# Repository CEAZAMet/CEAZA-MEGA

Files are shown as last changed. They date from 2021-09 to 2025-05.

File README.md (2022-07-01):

# CEAZA Mega   [][License]

*A reliable & expandable low power data <br>
logger for scientists, based on the Arduino.*

<br>
<br>

<div align = center>

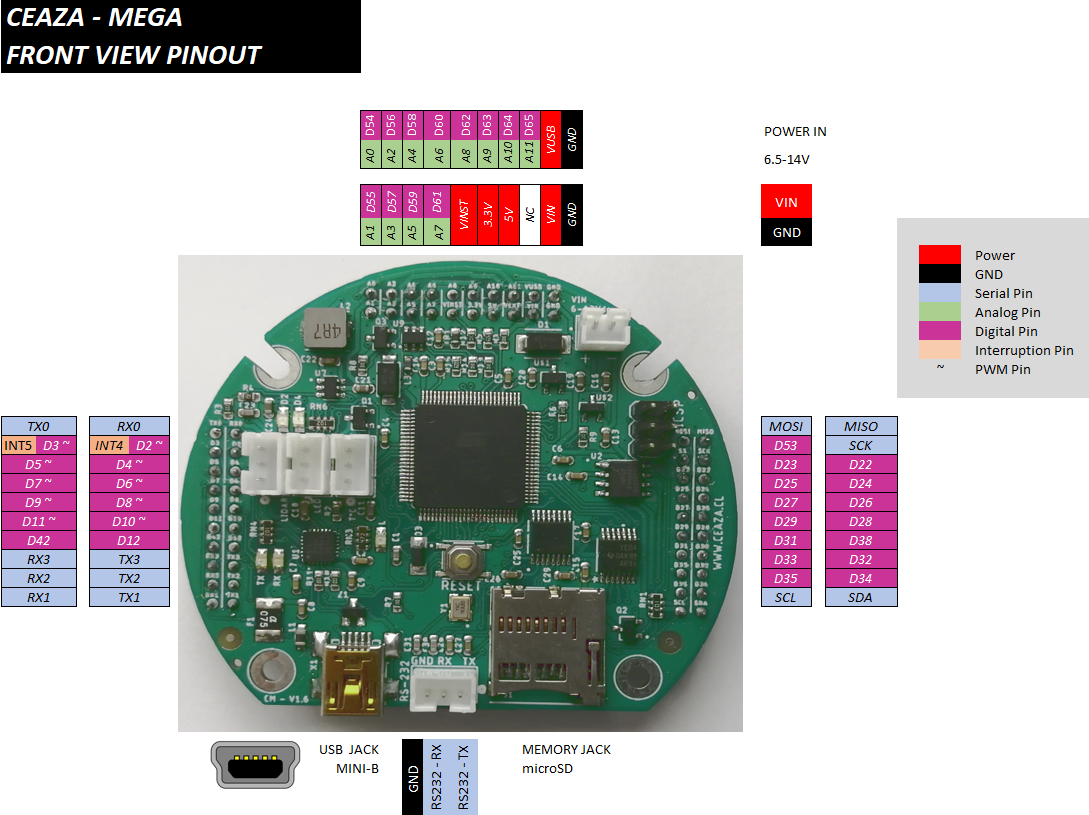
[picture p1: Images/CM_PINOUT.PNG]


</div>

<br>
<br>

## What It Is

Is a new simple, robust and expandable datalogger Arduino derivative board based in typical maker’s community integrations.  The board was designed and implemented taking into account requirements as low consumption, expandability and integration. Different tests where made so reliability in low temperatures and low energy needs are satisfied. 
Is expected that the scientific community can add this board to their tool set, as this board solves the energy problem and present an easy transition from handmade logger integrations.

CEAZA mega board integrate:
- ATMEGA2560 8-bit microcontroller
- Arduino mega 2560 bootloader for easy Arduino Ide compatibility
- A real time clock (RTC)
- A microSD card socket for data storage
- USB/Serial driver connected to UART0 for program as an Arduino mega or computer serial communication
- Serial RS-232 driver (connected to UART1) 
- Controlled high frequency (2MHz) step down switching regulator MP2451DT-LF-Z configured to deliver 5V and up to 600mA for external sensor
- Built in 10Kohm NTC thermistor for PCB temperature monitoring
- Power source system voltage monitor
- Terminal for direct connection with DS18B20 1-wire digittal temperature sensor
- 3 LEDs on board and external duplicate conection for two of those LEDs
- an ISCP terminal to program with external programer
- 3 expansion terminal for direct wires soldering or easy plug/unplug expansion boards for CEAZA MEGA

<br>

Furthermore, all integrated devices, except the main **MCU** <br>
uses a firmware controlled switched power supply in order <br>
to optimize de power consumption.

## Documentation

A comprehensive documentation for well understand, use <br>
or modify the **CEAZA MEGA** board is available in our Wiki. 

Additionally we share our schematic <br>
diagrams and Arduino example codes.

<br>
<br>

## Quickstart guide

1.  Connect a `6.5 - 14V` DC power supply.

2.  Connect the **CEAZA MEGA** main board to <br>
    the host PC with he mini-USB connector.

3.  Open the Arduino IDE.

4.  Select the Arduino Mega board <br>
    and the corresponding COM port.

5.  Open any of example sketches.

6.  Upload to the board.

<br>
<br>

## Contact & Support

For all kinds of inquiries, please contact me to <br>
my e-mail address: adrian.gallardo@ceaza.cl

<br>
<br>

## Contributing

You are welcome to contribute to the development <br>
or improvement of **CEAZA MEGA** hardware design <br>
or example application codes.

Feel free to submit a new pull request via **GitHub**.

<br>
<br>

## Academic Context

A paper with more details and performed tests was shown in **[DOI]**. 

<br>
<br>

## Disclaimer

Use **CEAZA MEGA** board and examples code at your own risk. <br>
We do not encourage any malicious use of our board.

<br>

<!----------------------------------------------------------------------------->

[Badge License]: https://img.shields.io/badge/License-MIT-yellow.svg?style=for-the-badge

[DOI]: http://doi.org/10.11591/ijres.v11.i2.pp175-187

[Preview]: Images/CM_PINOUT.PNG
[License]: LICENSE

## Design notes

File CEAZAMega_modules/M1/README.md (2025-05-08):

# Welcome to CEAZA-M1!
Wireless communication and memory backup expansion board for CEAZA MEGA.
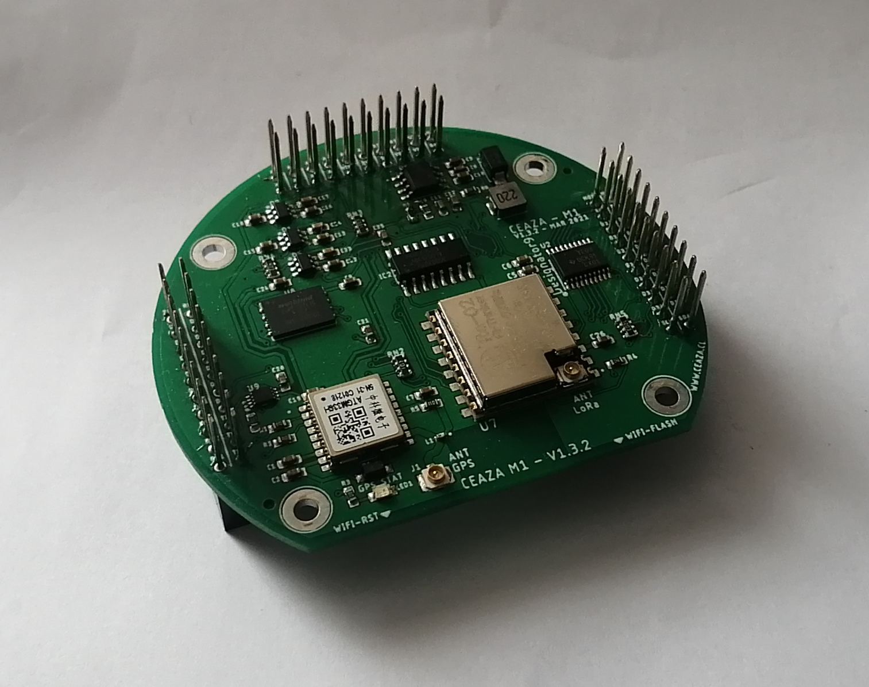
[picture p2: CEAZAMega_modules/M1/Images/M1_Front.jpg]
CEAZA M1 Board


## What is the CEAZA M1?

This design is an expansion board for CEAZA MEGA datalogger, which add the local wireless comumunication capability to the system.
The board Design integrates:
* An Ra-02 Ai-Thinker for 410-525MHz or Ra-01SH for 803MHz~930MHz LoRa Radio module.
* An ATGM336H-5N-31 GNSS GPS BDS positioning and navigation module.
* An ESP-12E WiFi module.
* A W25N01GVZEIG 1G-bit serial nand flash memory for redundant data storage.

All modules integratred are equiped with its respective power switch and power supply controlled by firmware for energy save when low power consumtions are required.
An on board jumper is included, ready to solder when the backup power source is required for GNSS module from permanent 3.3V available from CEAZA MEGA board, which increases 10uA the system power consumption.

The GNSS and WiFi modules share the same MCU UART2 thought an 74HC4052D analog multiplexer, which is controlled by firmware.

This board is pin compatible and should be connected to the CEAZA MEGA system to proper work.

## Documentation
A comprehensive documentation for well undertand, use or modify the CEAZA M1 board is available in our Wiki. In adition, we share with you the schematics diagrams, adns Arduino example codes.

## Quickstart guide
Install the M1 board in the CEAZA MEGA's bottom, make certain connection throuhg the boards by three 2 x 10 pin header terminals is rigth. 
Attach GNSS and LoRa antennas to the board, connect the power source 7 to 14 Vdc to the system.
Connect the CEAZA MEGA main board system to the host PC by mini-USB connector, open the Arduino ide software, select the Arduino Mega board and the correspondign COM port.

Open any of examples scketches and upload to the board.

# Contact and support
For all kinds of inquiries, please contact me to my e-mail address: adrian.gallardo@ceaza.cl

# Contributing
You are welcome to contribute to the development or improvement of M1 hardware design or example application codes. Feel free to submit a new pull request via github.

# Academic Context

# Licensing

# Disclaimer
Use M1 board and examples code at your own risk. We do not encourage any malicious use of our board.

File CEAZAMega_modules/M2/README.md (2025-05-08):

# Welcome to CEAZA-M2!
Prototyping board for CEAZA MEGA system.
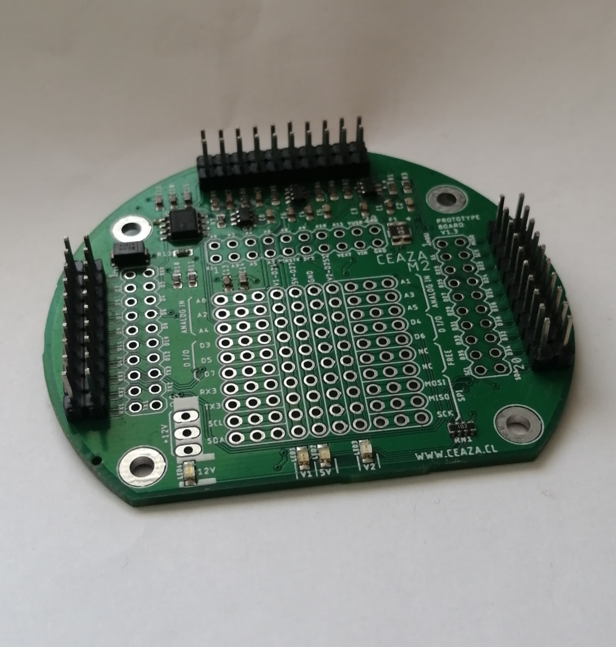
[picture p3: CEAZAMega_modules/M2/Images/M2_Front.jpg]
CEAZA M2 Board


# What is the CEAZA-M2?
Is a prototyping board with a firmware controlled +5V dedicated step-down power supply and controlled Vin pin for CEAZA MEGA system.
The board give you access to some pins as a PCB breadboard format, ready to solder any module or device.
Furthermore the board have a duplicate I/O expansion terminals to give you direct access to any of its pins.
Whith CEAZA M2 board you can easyly integrate any device to CEAZA MEGA system without any other customized board.

## Documentation
A comprehensive documentation for well undertand, use or modify the CEAZA M2 board is available in our Wiki. In adition, we share with you the schematics diagrams, adns Arduino example codes.

## Quickstart guide
Plan your electronic conection to your device, solder the necesay wires to connect your devices in the M2 board.
Install the M2 board in the CEAZA MEGA's bottom, make certain connection throuhg the boards by three 2 x 10 pin header terminals is rigth. Plug the battery and solar panel cables in the respective board terminal. be careful to avoid swap both plugs, due they are the same type of terminals. Connect the CEAZA MEGA main board system to the host PC by mini-USB connector, open the Arduino ide software, select the Arduino Mega board and the correspondign COM port.
Open any of examples scketches and upload to the board.
### WARNING!
Be careful with your breadboard conections due exist a posibility of a shortcircuit of the power supply acces in the breadboard. 
A 1A PTC Resettable fuse is placed in the main electric supply to the board (VIN pin od I/O expansion terminal) for extra electric protection.

# Contact and support
For all kinds of inquiries, please contact me to my e-mail address: adrian.gallardo@ceaza.cl

# Contributing
You are welcome to contribute to the development or improvement of M2 hardware design or example application codes. Feel free to submit a new pull request via github.

# Academic Context

# Licensing

# Disclaimer
Use M2 board and examples code at your own risk. We do not encourage any malicious use of our board.

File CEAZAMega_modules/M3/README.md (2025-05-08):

# Welcome to CEAZA-M3!
Solar charger for 12V SLA battery in CEAZA MEGA system.
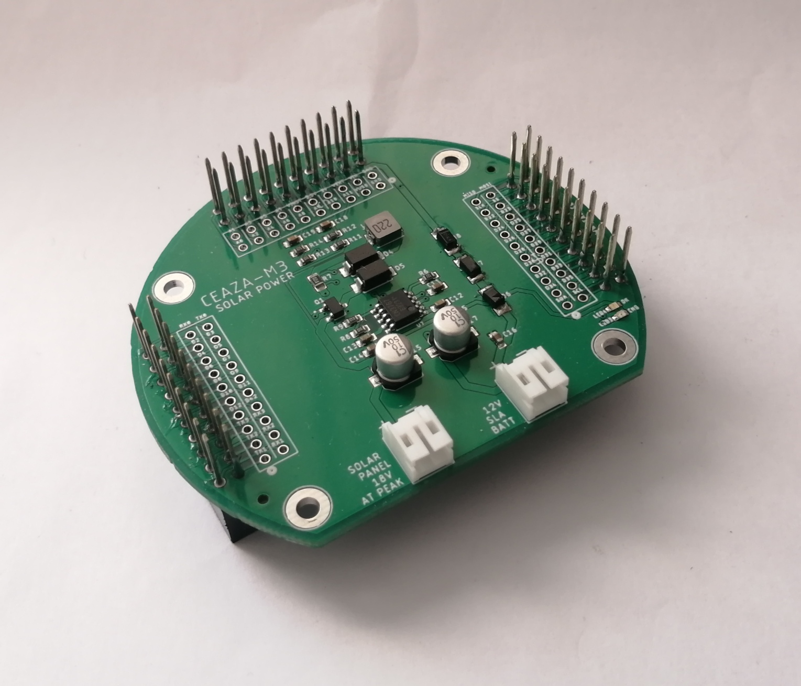
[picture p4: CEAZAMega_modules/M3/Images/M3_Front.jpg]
CEAZA M3 Board


# What is the CEAZA-M3?
Is a solar PWM charger for 12V SLA battery board compatible with CEAZA MEGA system, which allow recharge the system battery every day and avoid system failure due lack of energy storage.
The CEAZA M3 have below specs:
- Only for 12V SLA batteries.
- 18Vmpp Solar pannel (absolute maximum 28V)
- Solar pannel voltage monitor.
- Battery voltage monitor.
- Status LED red and green powered from solar panel which indicates charging or done respectively.
- Ready to solder pins for easy prototyping.

This board is pin compatible and should be connected to the CEAZA MEGA system to proper work.

## Documentation
A comprehensive documentation for well undertand, use or modify the CEAZA M3 board is available in our Wiki. In adition, we share with you the schematics diagrams, adns Arduino example codes.

## Quickstart guide
Install the M3 board in the CEAZA MEGA's bottom, make certain connection throuhg the boards by three 2 x 10 pin header terminals is rigth. Plug the battery and solar panel cables in the respective board terminal. be careful to avoid swap both plugs, due they are the same type of terminals. Connect the CEAZA MEGA main board system to the host PC by mini-USB connector, open the Arduino ide software, select the Arduino Mega board and the correspondign COM port.
Open any of examples scketches and upload to the board.
### WARNING!
Do not connect the battery in the main CEAZA MEGA power plug when you connect the M3 board. This may cause an electric problem in the system.

# Contact and support
For all kinds of inquiries, please contact me to my e-mail address: adrian.gallardo@ceaza.cl

# Contributing
You are welcome to contribute to the development or improvement of M3 hardware design or example application codes. Feel free to submit a new pull request via github.

# Academic Context

# Licensing

# Disclaimer
Use M3 board and examples code at your own risk. We do not encourage any malicious use of our board.

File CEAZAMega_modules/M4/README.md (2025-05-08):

# CEAZA-M4
Solar charger for 3.7V lithium battery in CEAZA MEGA system.

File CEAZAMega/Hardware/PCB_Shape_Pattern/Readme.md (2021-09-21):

# CEAZA mega PCB Shape Pattern
You can design your own CEAZAmega expansion board which could comply with your functional requirements.
Here they're available the eagle documents to develop a shape compatible new expansion board.

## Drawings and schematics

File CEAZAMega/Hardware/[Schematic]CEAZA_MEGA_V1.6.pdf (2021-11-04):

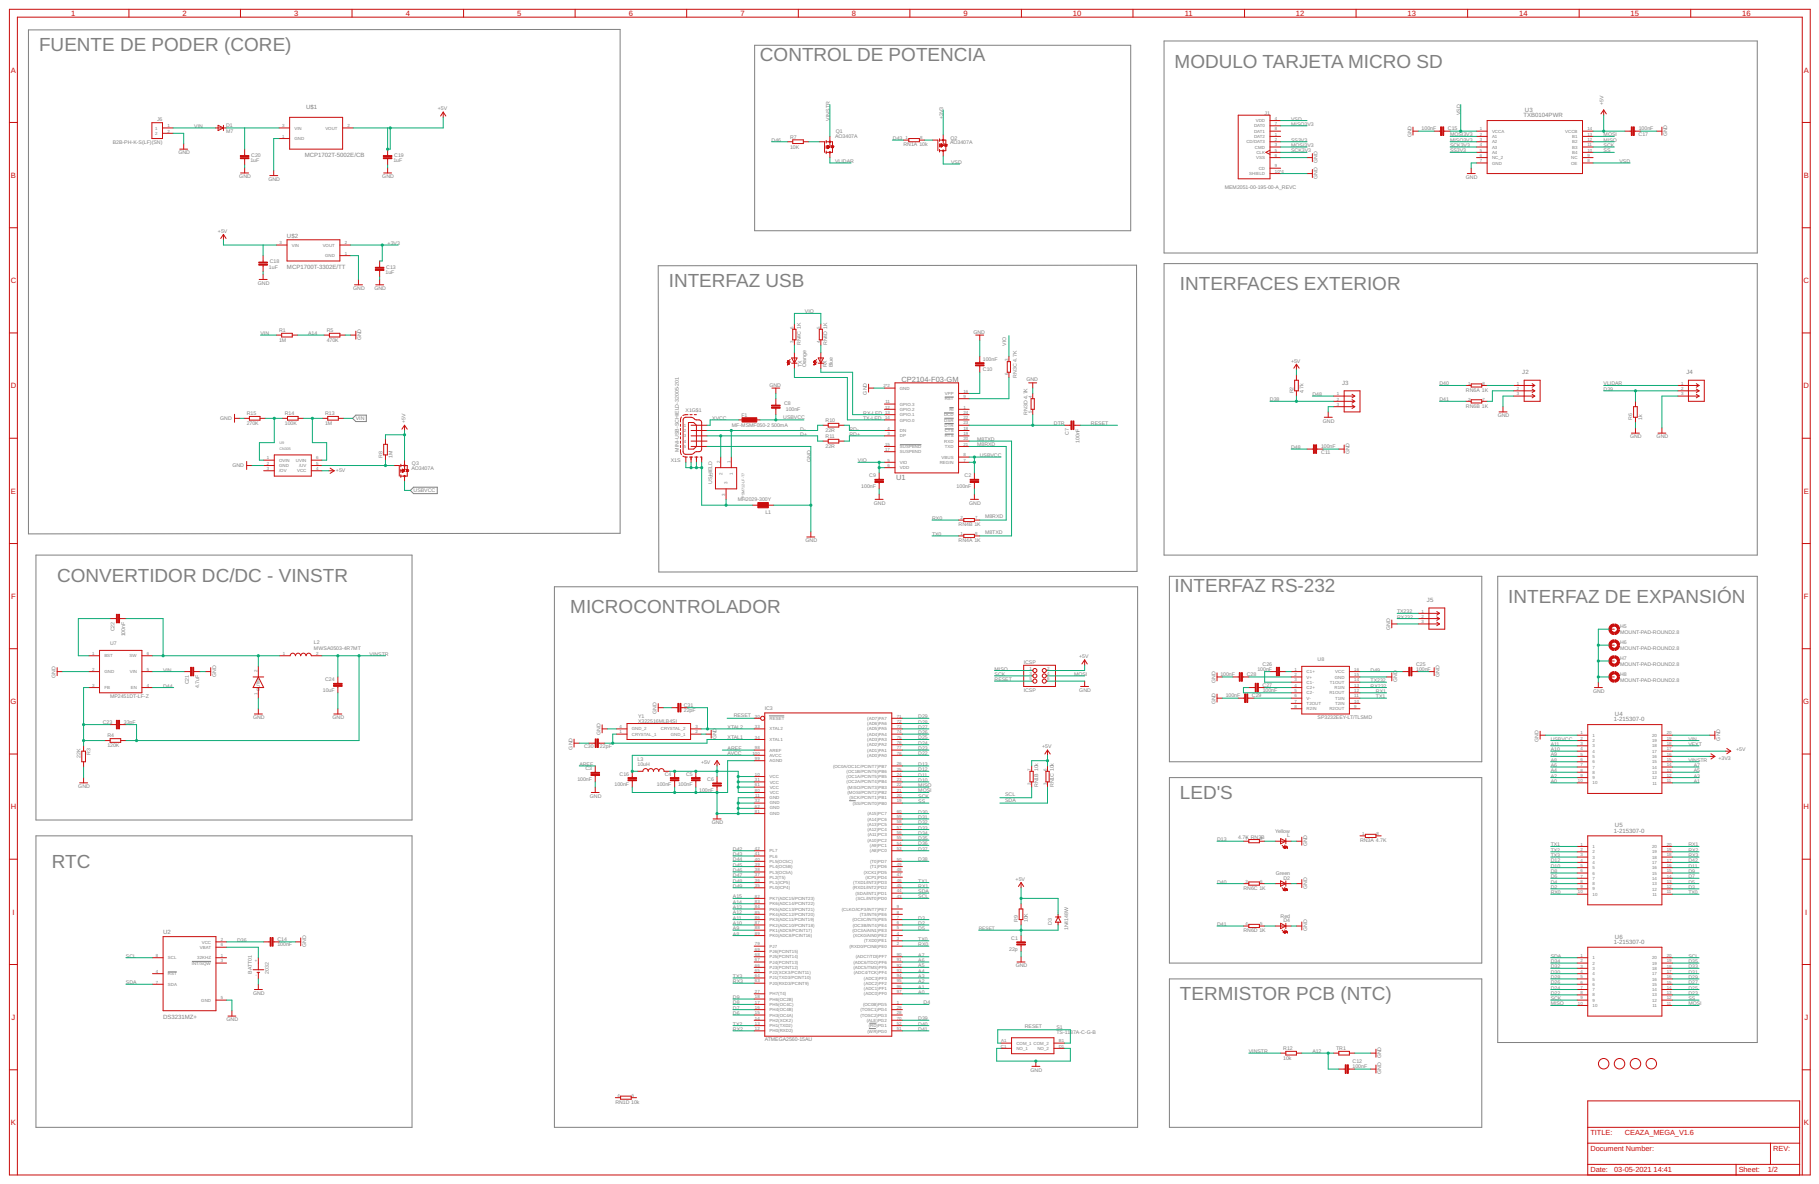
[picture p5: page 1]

FUENTE DE PODER (CORE)

SpiceOrder 1 SpiceOrder 2 MODULO TARJETA MICRO SD

CONVERTIDOR DC/DC - VINSTR

MOUNT-PAD-ROUND2.8 MOUNT-PAD-ROUND2.8 MOUNT-PAD-ROUND2.8 MOUNT-PAD-ROUND2.8 1-215307-0

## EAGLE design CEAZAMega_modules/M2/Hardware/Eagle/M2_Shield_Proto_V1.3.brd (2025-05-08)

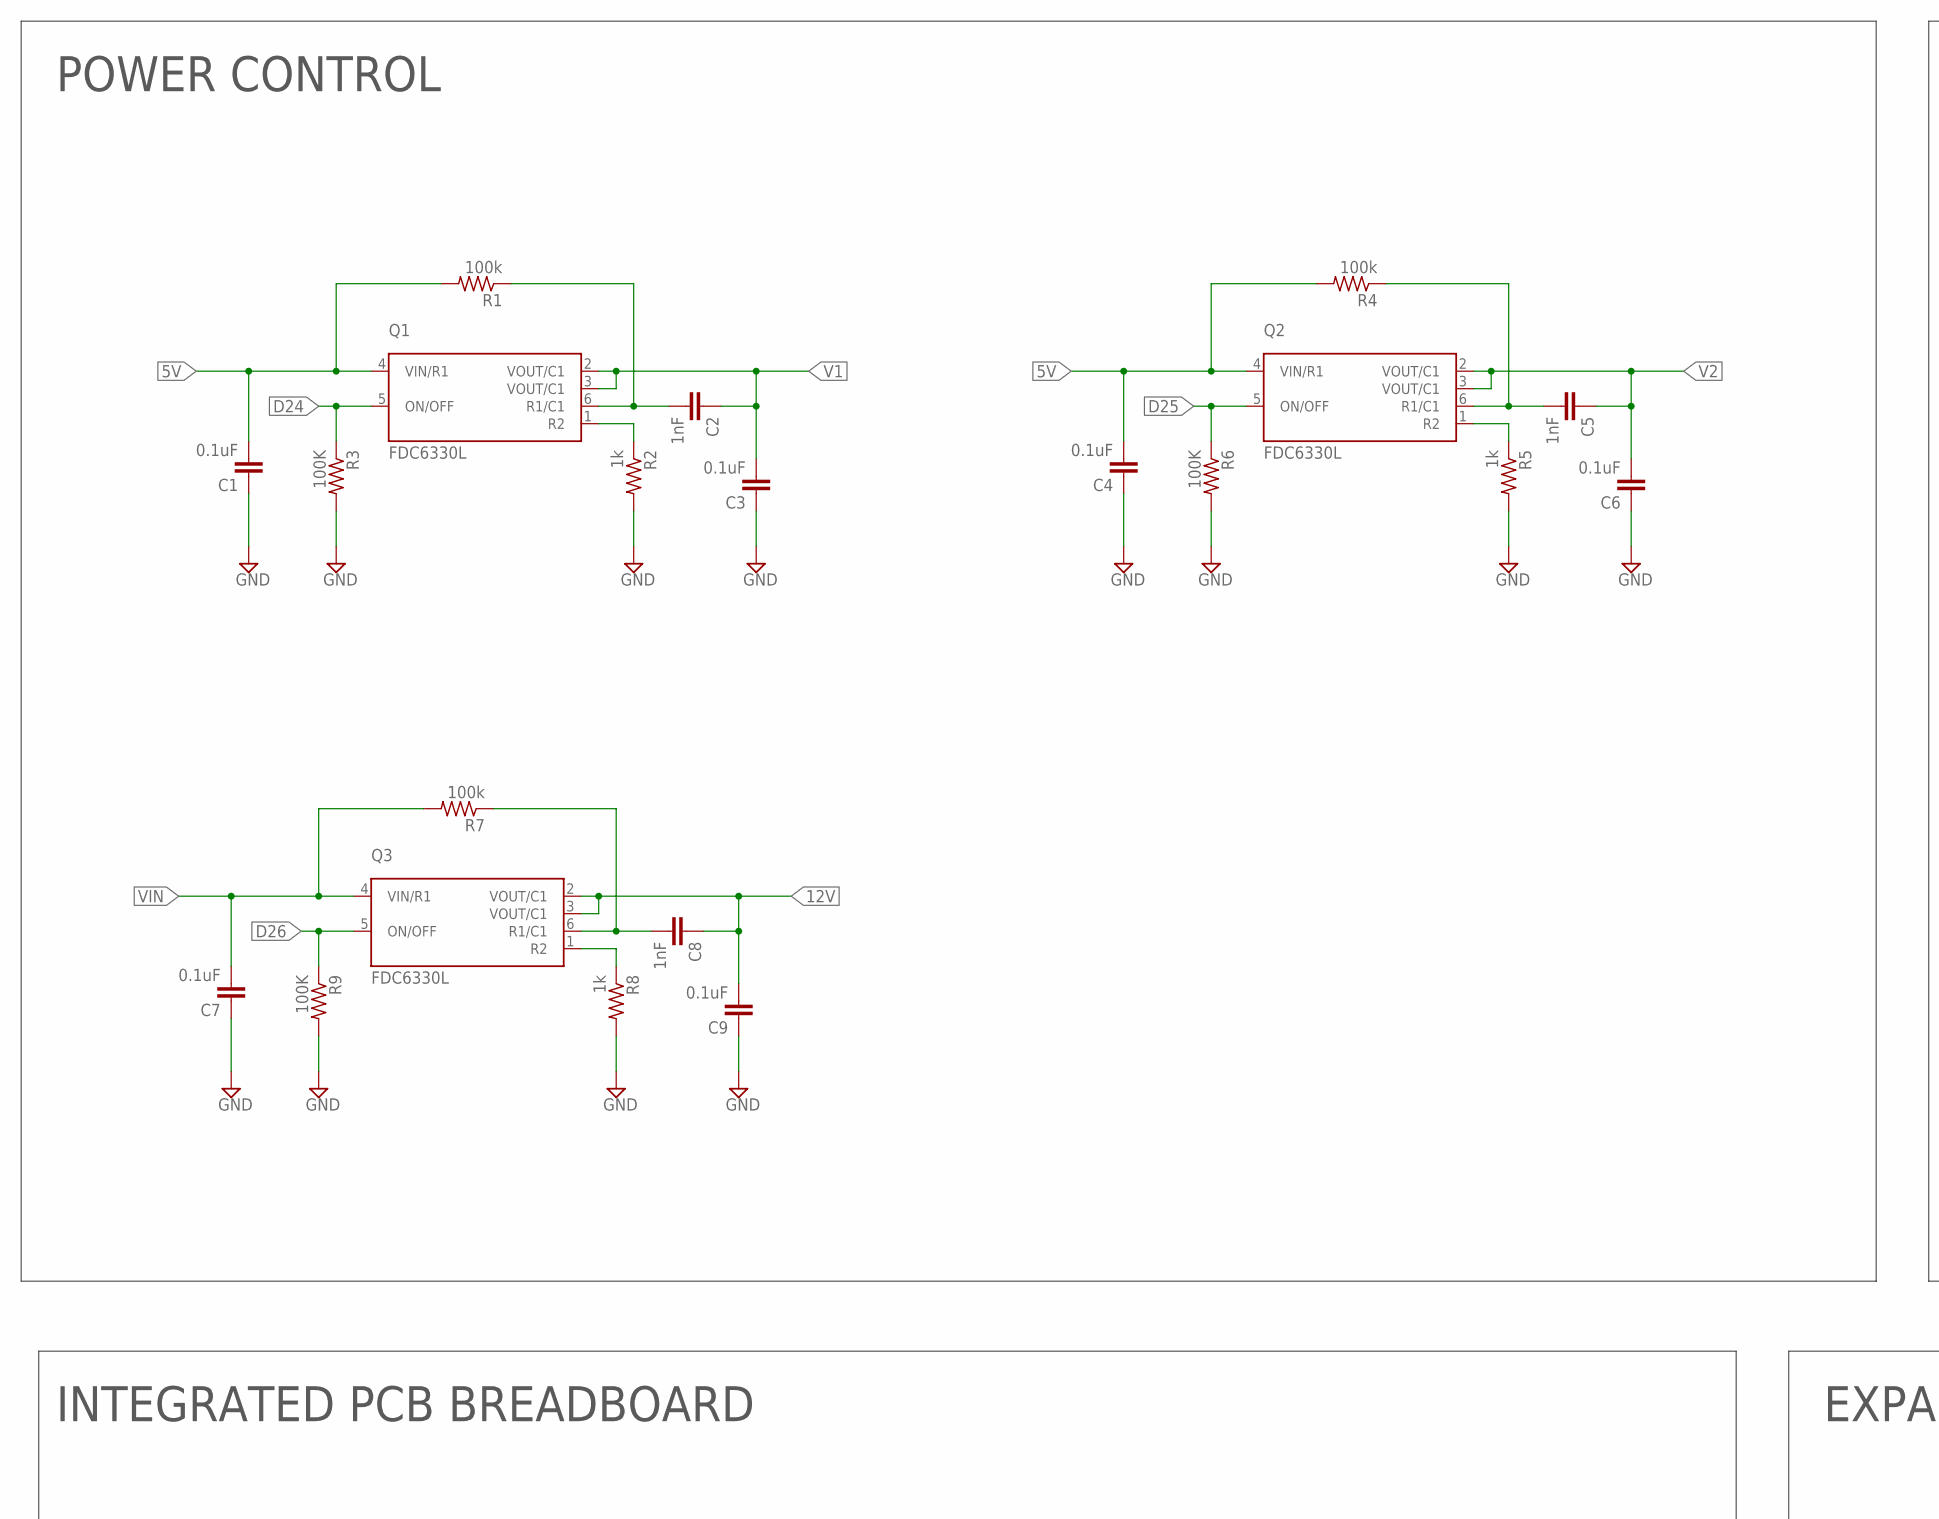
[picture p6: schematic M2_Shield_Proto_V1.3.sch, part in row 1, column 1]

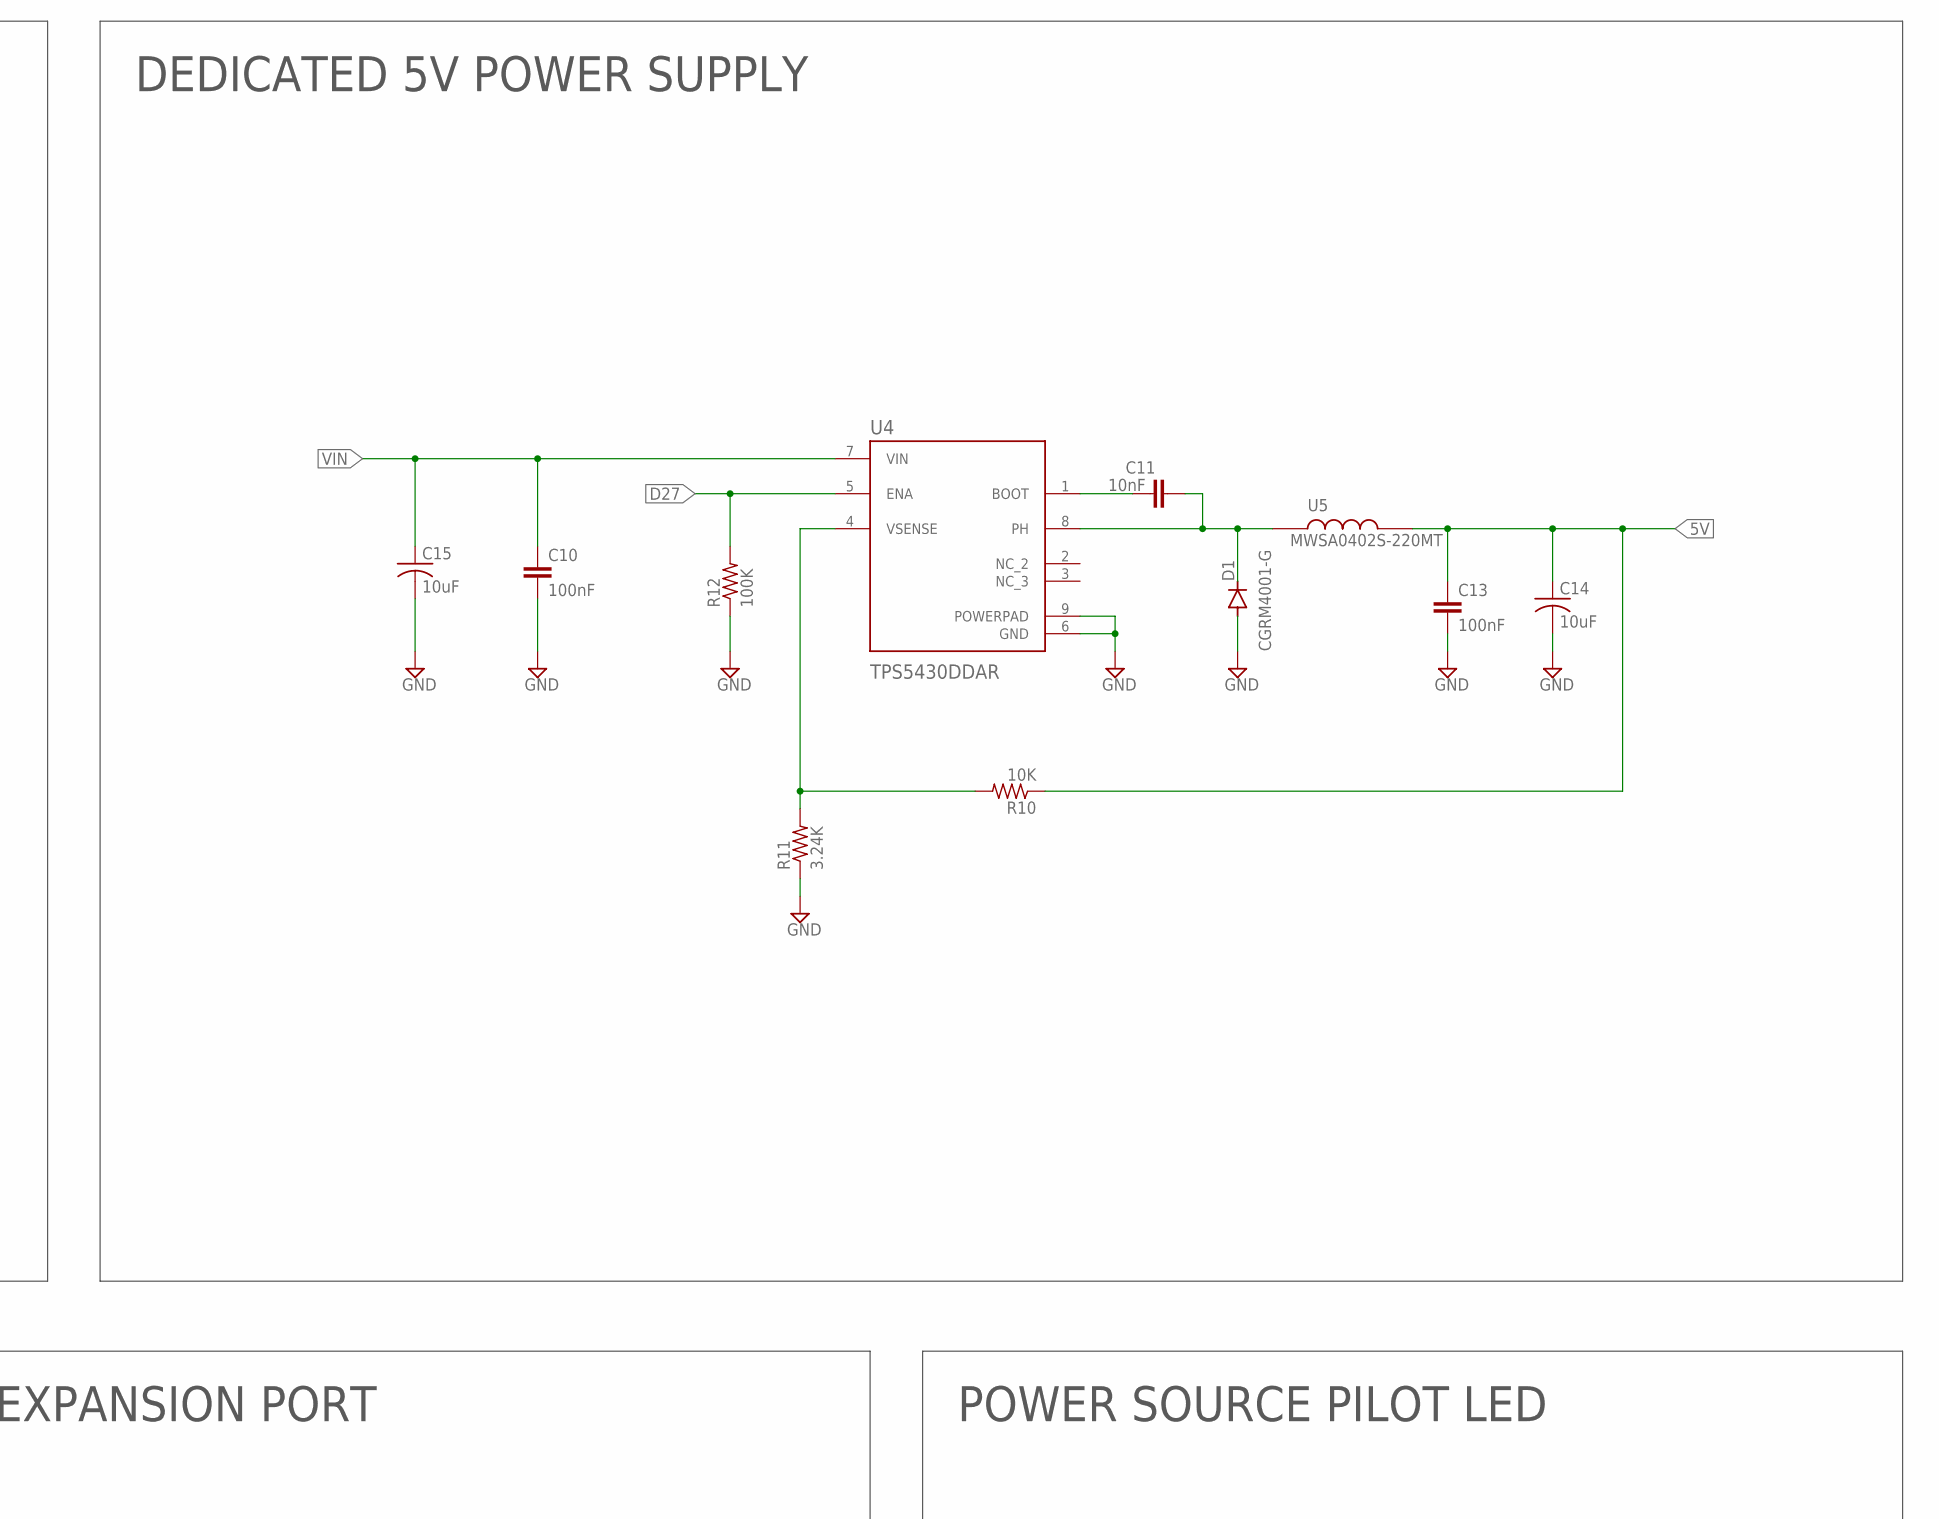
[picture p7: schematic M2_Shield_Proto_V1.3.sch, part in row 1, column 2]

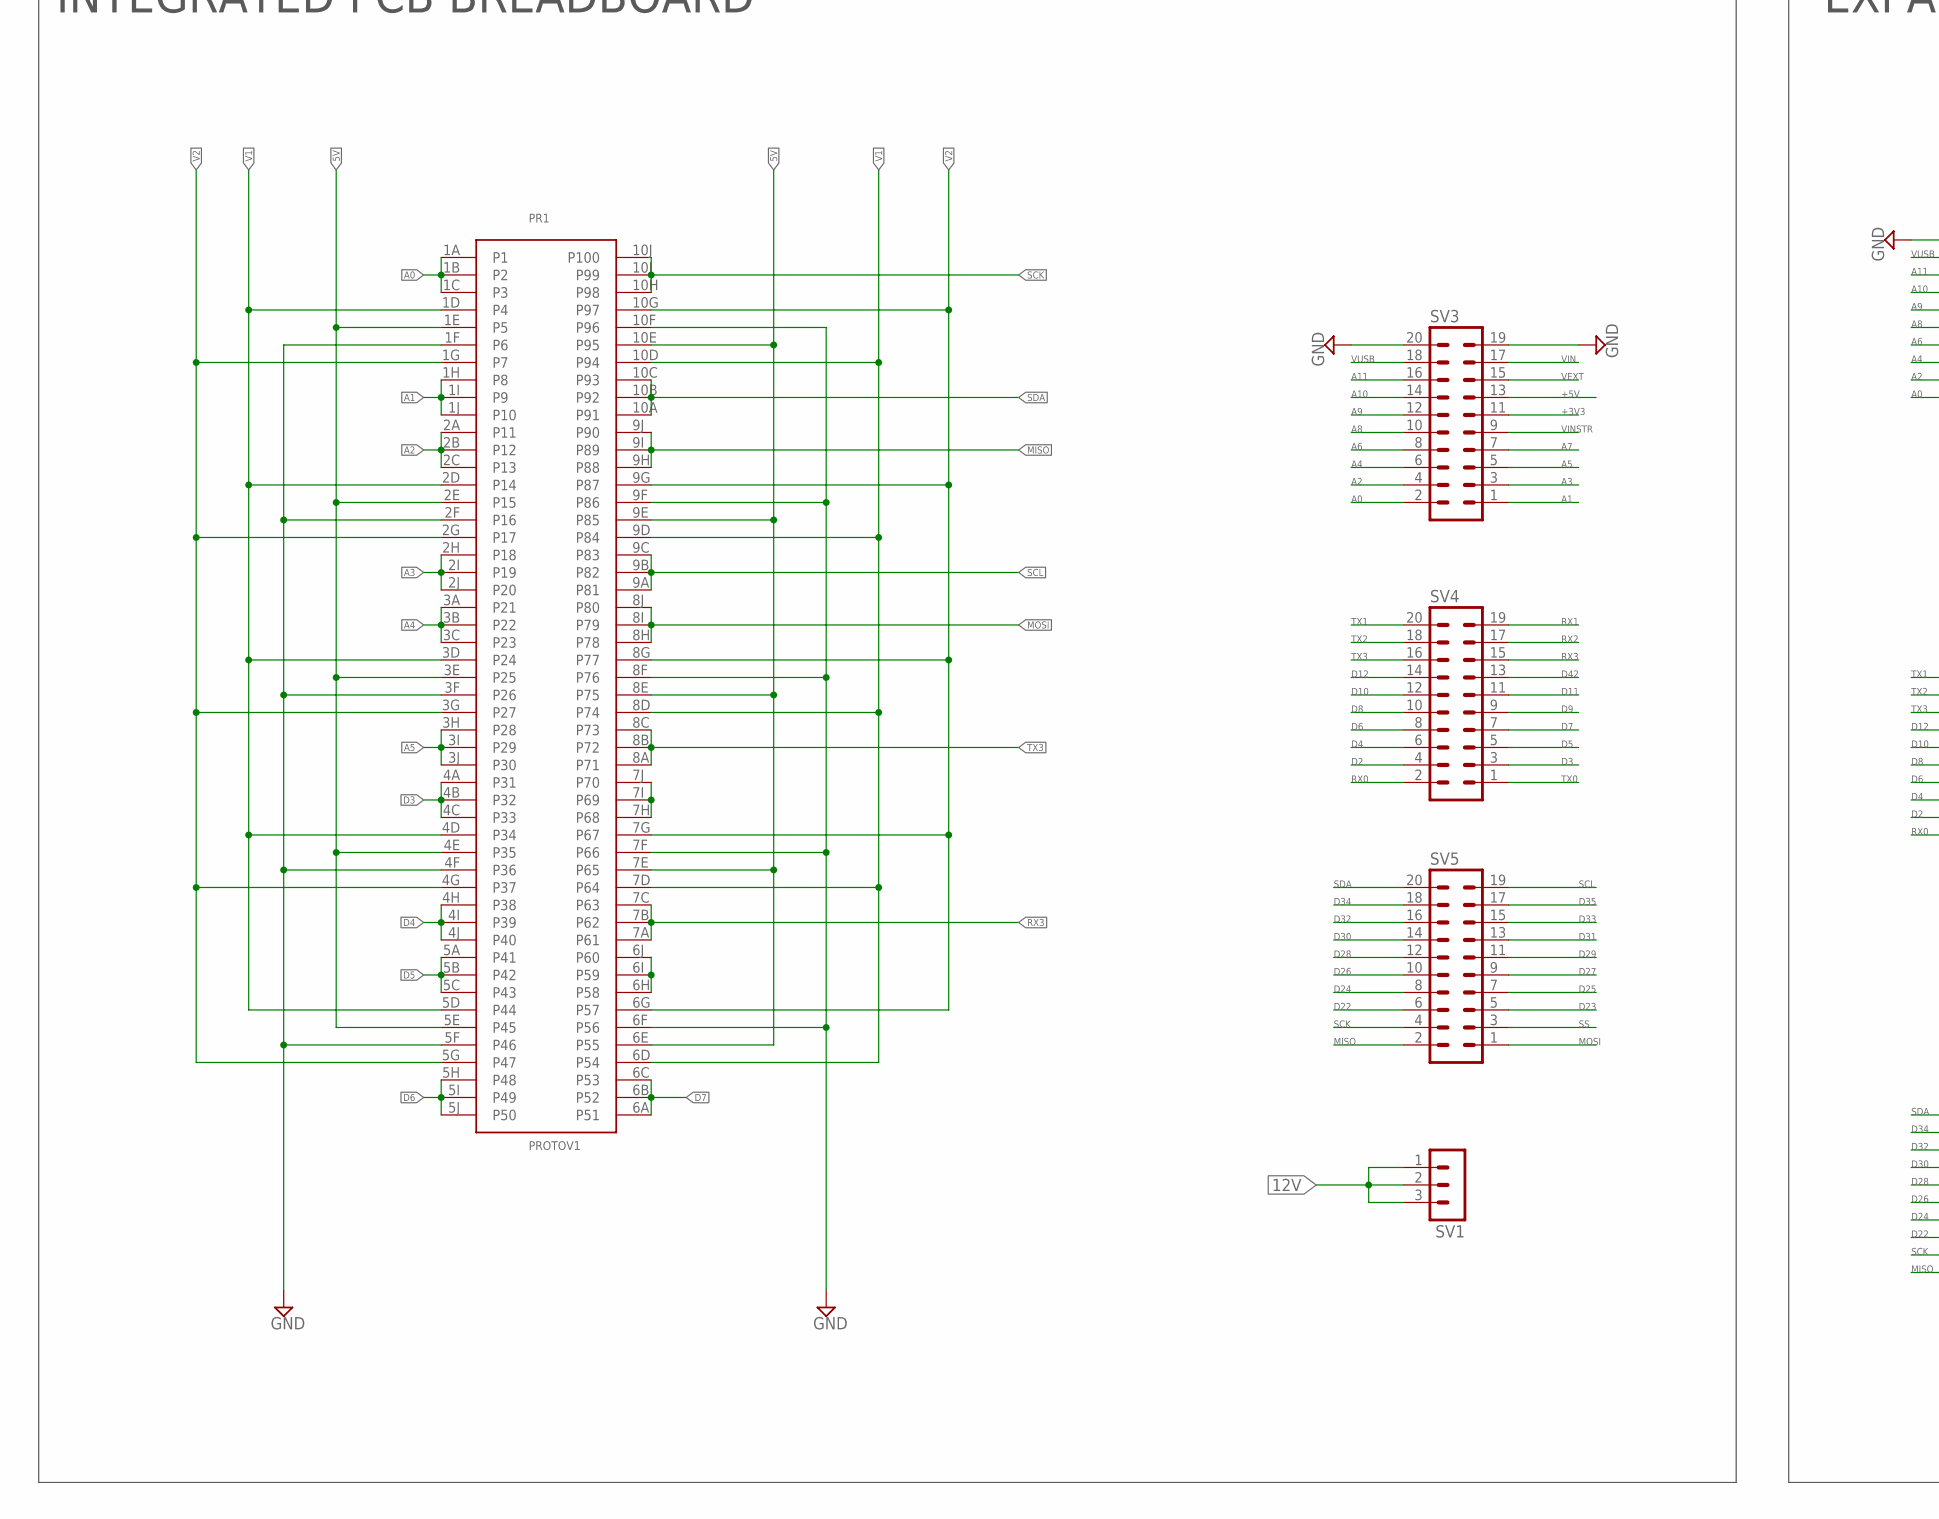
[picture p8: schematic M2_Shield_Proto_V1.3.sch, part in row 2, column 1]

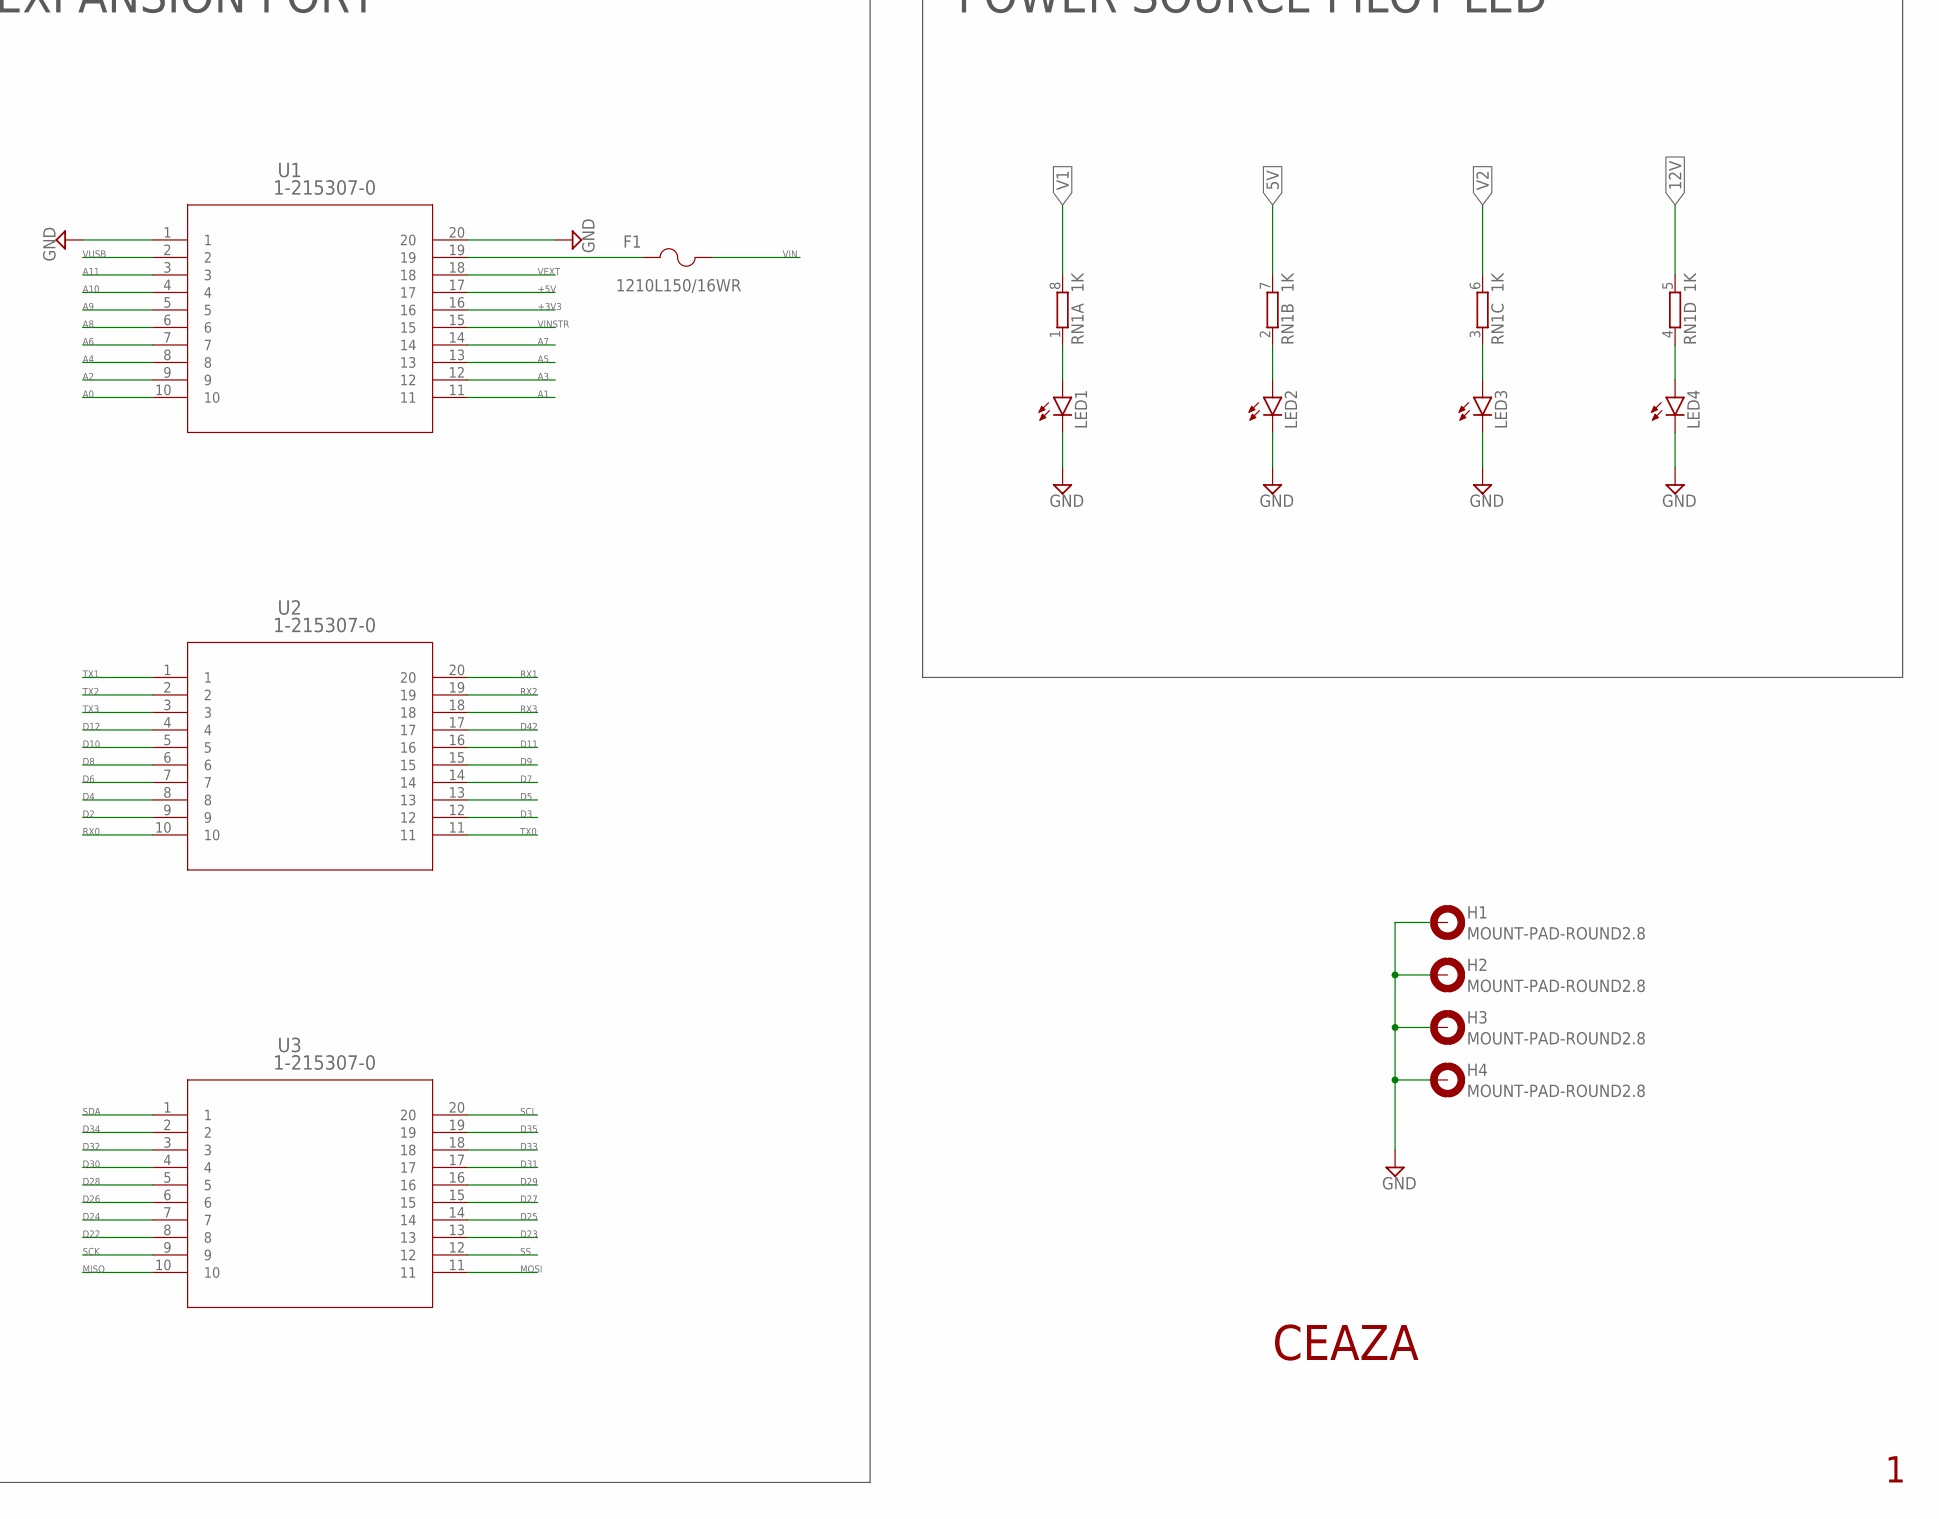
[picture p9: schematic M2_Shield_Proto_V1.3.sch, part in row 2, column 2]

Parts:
C1, C3, C4, C6, C7, C9: 0.1uF; C0603
C2, C5, C8: 1nF; C0603
C10, C13: 100nF; C0603
C11: 10nF; C0603
C14, C15: 10uF; C0603
D1: CGRM4001-G; SOD-123_MINI-SMA
F1: 1210L150/16WR; 1210LSERIES
H1, H2, H3, H4: MOUNT-PAD-ROUND2.8; 2,8-PAD
LED1, LED2, LED3, LED4: LEDCHIP-LED0805; CHIP-LED0805
PR1: PROTOV1
Q1, Q2, Q3: FDC6330L; SOT95P280X110-6N
R1, R4, R7: 100k; R0603
R2, R5, R8: 1k; R0603
R3, R6, R9, R12: 100K; R0603
R10: 10K; R0603
R11: 3.24K; R0603
RN1: 1K; 0603-ARV
SV1: MA03-1
SV3, SV4, SV5: MA10-2
U1, U2, U3: 1-215307-0
U4: TPS5430DDAR; CONV_TPS5430DDAR
U5: MWSA0402S-220MT

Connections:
5V: C1.2, C4.2, C13.1, C14.1, PR1.1E (P5), PR1.2E (P15), PR1.3E (P25), PR1.4E (P35), PR1.5E (P45), PR1.6E (P55), PR1.7E (P65), PR1.8E (P75), PR1.9E (P85), PR1.10E (P95), Q1.4 (VIN/R1), Q2.4 (VIN/R1), R1.2, R4.2, R10.1, RN1.7 (2), U5.P$2
12V: C8.1, C9.2, Q3.2 (VOUT/C1), Q3.3 (VOUT/C1), RN1.5 (2), SV1.1, SV1.2, SV1.3
+3V3: SV3.11, U1.16
+5V: SV3.13, U1.17
A0: PR1.1A (P1), PR1.1B (P2), PR1.1C (P3), SV3.2, U1.10
A1: PR1.1H (P8), PR1.1I (P9), PR1.1J (P10), SV3.1, U1.11
A2: PR1.2A (P11), PR1.2B (P12), PR1.2C (P13), SV3.4, U1.9
A3: PR1.2H (P18), PR1.2I (P19), PR1.2J (P20), SV3.3, U1.12
A4: PR1.3A (P21), PR1.3B (P22), PR1.3C (P23), SV3.6, U1.8
A5: PR1.3H (P28), PR1.3I (P29), PR1.3J (P30), SV3.5, U1.13
A6: SV3.8, U1.7
A7: SV3.7, U1.14
A8: SV3.10, U1.6
A9: SV3.12, U1.5
A10: SV3.14, U1.4
A11: SV3.16, U1.3
D2: SV4.4, U2.9
D3: PR1.4A (P31), PR1.4B (P32), PR1.4C (P33), SV4.3, U2.12
D4: PR1.4H (P38), PR1.4I (P39), PR1.4J (P40), SV4.6, U2.8
D5: PR1.5A (P41), PR1.5B (P42), PR1.5C (P43), SV4.5, U2.13
D6: PR1.5H (P48), PR1.5I (P49), PR1.5J (P50), SV4.8, U2.7
D7: PR1.6A (P51), PR1.6B (P52), PR1.6C (P53), SV4.7, U2.14
D8: SV4.10, U2.6
D9: SV4.9, U2.15
D10: SV4.12, U2.5
D11: SV4.11, U2.16
D12: SV4.14, U2.4
D22: SV5.6, U3.8
D23: SV5.5, U3.13
D24: Q1.5 (ON/OFF), R3.1, SV5.8, U3.7
D25: Q2.5 (ON/OFF), R6.1, SV5.7, U3.14
D26: Q3.5 (ON/OFF), R9.1, SV5.10, U3.6
D27: R12.2, SV5.9, U3.15, U4.5 (ENA)
D28: SV5.12, U3.5
D29: SV5.11, U3.16
D30: SV5.14, U3.4
D31: SV5.13, U3.17
D32: SV5.16, U3.3
D33: SV5.15, U3.18
D34: SV5.18, U3.2
D35: SV5.17, U3.19
D42: SV4.13, U2.17
GND: C1.1, C3.1, C4.1, C6.1, C7.1, C9.1, C10.2, C13.2, C14.2, C15.2, D1.A, H1.B2,8, H2.B2,8, H3.B2,8, H4.B2,8, LED1.C, LED2.C, LED3.C, LED4.C, PR1.1F (P6), PR1.2F (P16), PR1.3F (P26), PR1.4F (P36), PR1.5F (P46), PR1.6F (P56), PR1.7F (P66), PR1.8F (P76), PR1.9F (P86), PR1.10F (P96), R2.2, R3.2, R5.2, R6.2, R8.2, R9.2, R11.1, R12.1, SV3.19, SV3.20, U1.1, U1.20, U4.6 (GND), U4.9 (POWERPAD)
MISO: PR1.9H (P88), PR1.9I (P89), PR1.9J (P90), SV5.2, U3.10
MOSI: PR1.8H (P78), PR1.8I (P79), PR1.8J (P80), SV5.1, U3.11
unnamed: C11.1, U4.1 (BOOT)
unnamed: LED1.A, RN1.1
unnamed: LED2.A, RN1.2 (1)
unnamed: LED3.A, RN1.3 (1)
unnamed: LED4.A, RN1.4 (1)
unnamed: C11.2, D1.C, U4.8 (PH), U5.P$1
unnamed: C2.2, Q1.6 (R1/C1), R1.1
unnamed: Q1.1 (R2), R2.1
unnamed: C5.2, Q2.6 (R1/C1), R4.1
unnamed: Q2.1 (R2), R5.1
unnamed: PR1.6H (P58), PR1.6I (P59), PR1.6J (P60)
unnamed: PR1.7H (P68), PR1.7I (P69), PR1.7J (P70)
unnamed: R10.2, R11.2, U4.4 (VSENSE)
unnamed: C8.2, Q3.6 (R1/C1), R7.1
unnamed: Q3.1 (R2), R8.1
unnamed: F1.1, U1.19
RX0: SV4.2, U2.10
RX1: SV4.19, U2.20
RX2: SV4.17, U2.19
RX3: PR1.7A (P61), PR1.7B (P62), PR1.7C (P63), SV4.15, U2.18
SCK: PR1.10H (P98), PR1.10I (P99), PR1.10J (P100), SV5.4, U3.9
SCL: PR1.9A (P81), PR1.9B (P82), PR1.9C (P83), SV5.19, U3.20
SDA: PR1.10A (P91), PR1.10B (P92), PR1.10C (P93), SV5.20, U3.1
SS: SV5.3, U3.12
TX0: SV4.1, U2.11
TX1: SV4.20, U2.1
TX2: SV4.18, U2.2
TX3: PR1.8A (P71), PR1.8B (P72), PR1.8C (P73), SV4.16, U2.3
V1: C2.1, C3.2, PR1.1D (P4), PR1.2D (P14), PR1.3D (P24), PR1.4D (P34), PR1.5D (P44), PR1.6D (P54), PR1.7D (P64), PR1.8D (P74), PR1.9D (P84), PR1.10D (P94), Q1.2 (VOUT/C1), Q1.3 (VOUT/C1), RN1.8 (2)
V2: C5.1, C6.2, PR1.1G (P7), PR1.2G (P17), PR1.3G (P27), PR1.4G (P37), PR1.5G (P47), PR1.6G (P57), PR1.7G (P67), PR1.8G (P77), PR1.9G (P87), PR1.10G (P97), Q2.2 (VOUT/C1), Q2.3 (VOUT/C1), RN1.6 (2)
VEXT: SV3.15, U1.18
VIN: C7.2, C10.1, C15.1, F1.2, Q3.4 (VIN/R1), R7.2, SV3.17, U4.7 (VIN)
VINSTR: SV3.9, U1.15
VUSB: SV3.18, U1.2

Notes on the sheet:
DEDICATED 5V POWER SUPPLY
POWER CONTROL
INTEGRATED PCB BREADBOARD
EXPANSION PORT
POWER SOURCE PILOT LED
CEAZA

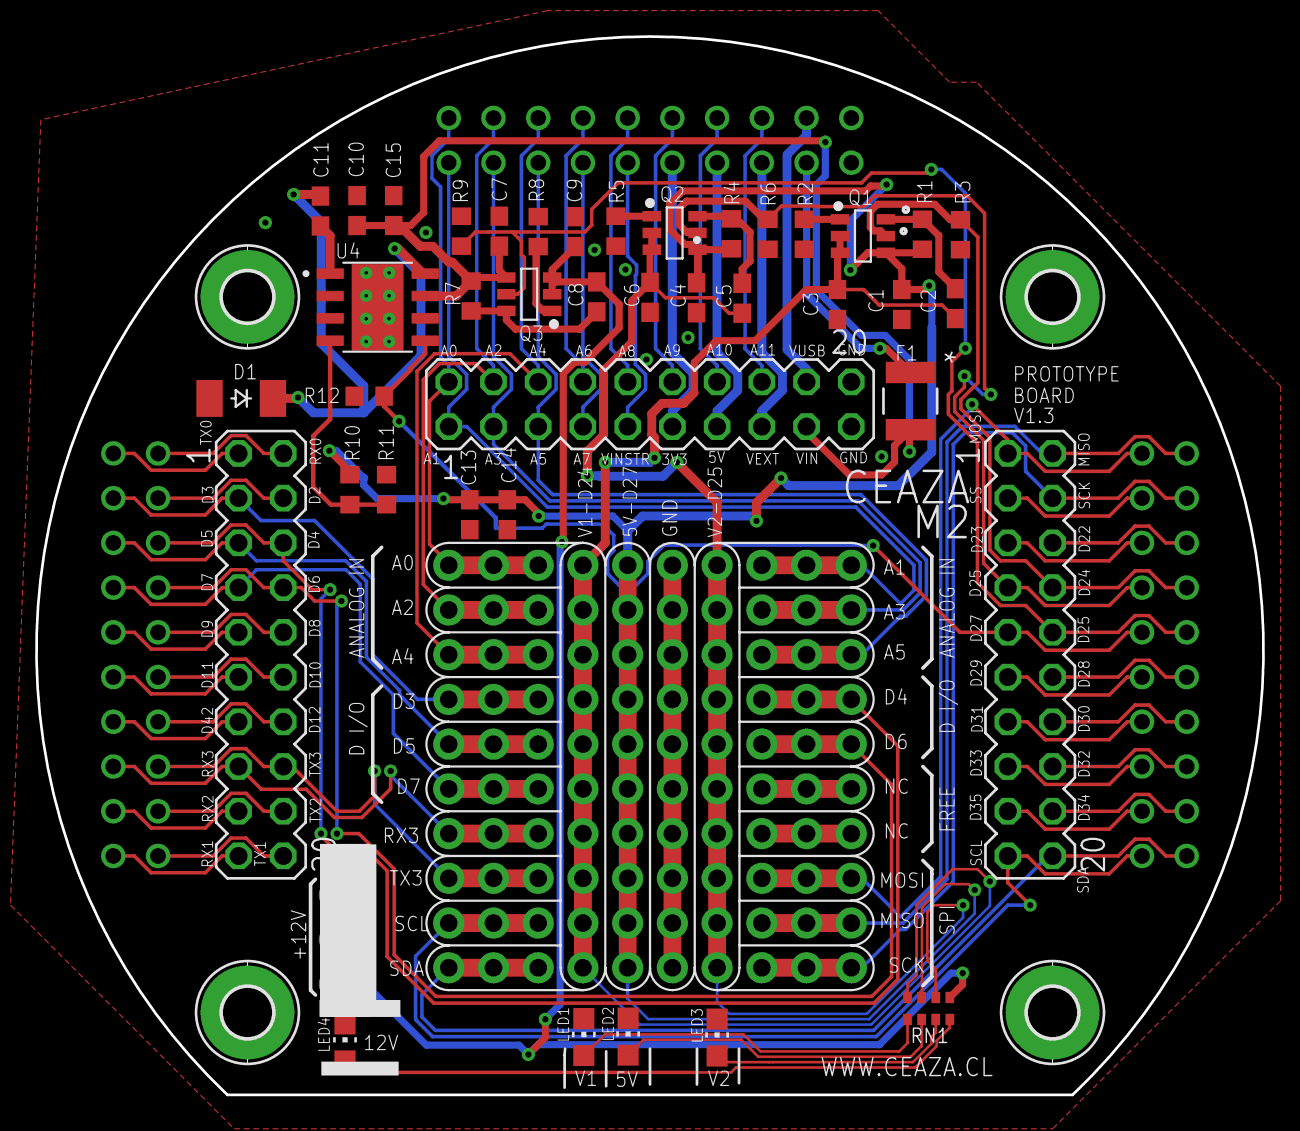
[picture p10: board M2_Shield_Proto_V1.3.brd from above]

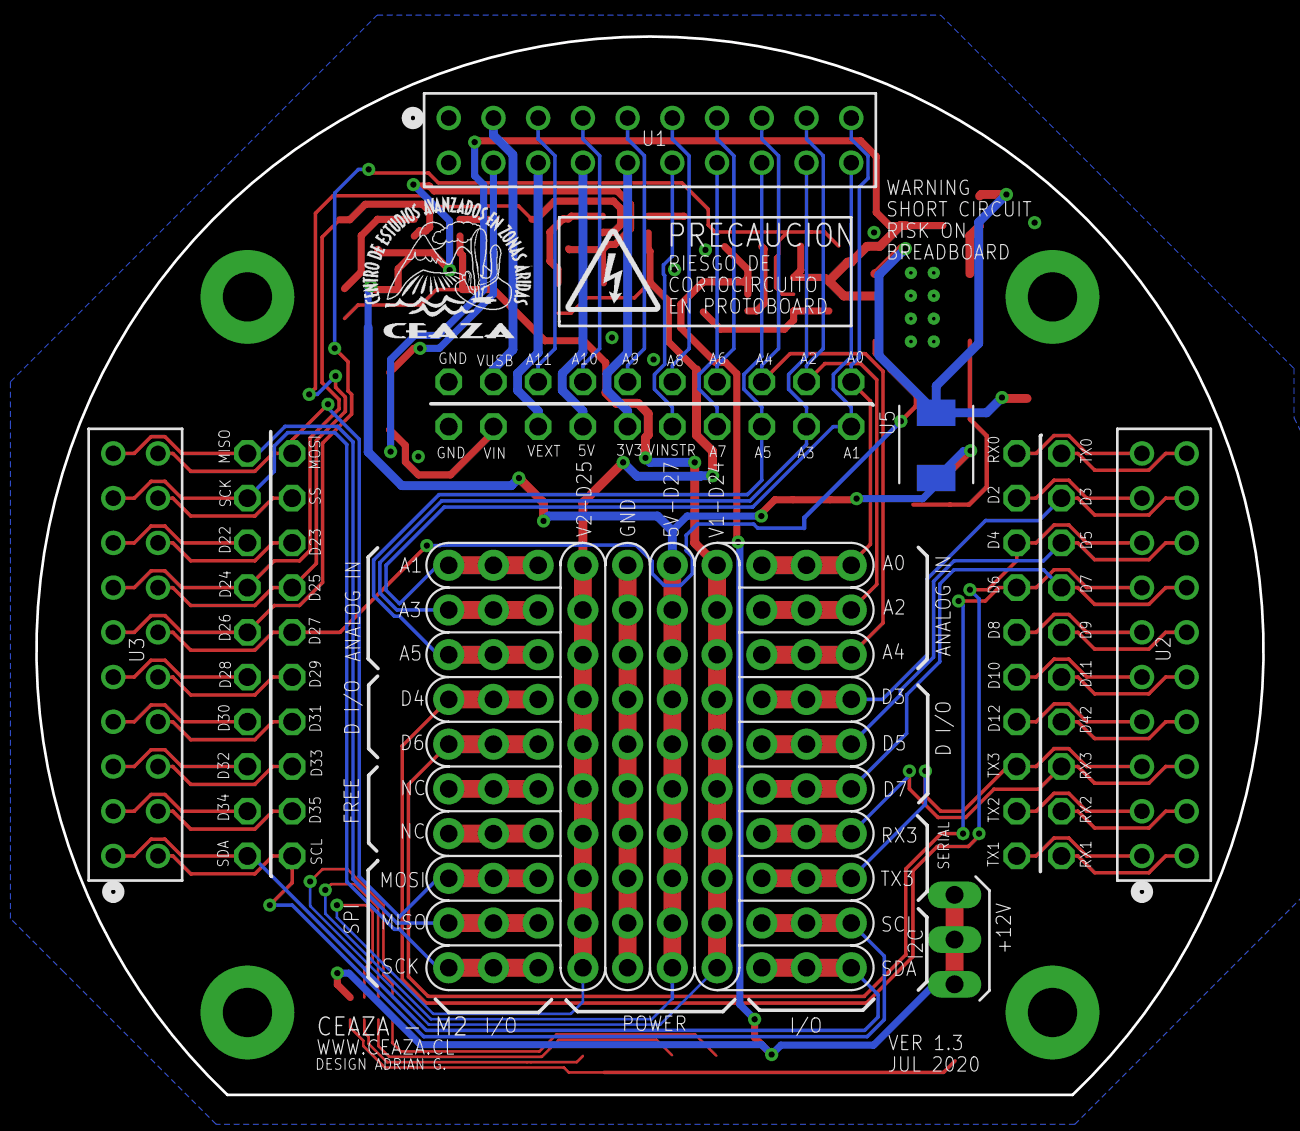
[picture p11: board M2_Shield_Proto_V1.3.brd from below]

Board: 2 copper layers, 69.7 x 60.1 mm, 50 parts (4 on the bottom side), 79 nets.

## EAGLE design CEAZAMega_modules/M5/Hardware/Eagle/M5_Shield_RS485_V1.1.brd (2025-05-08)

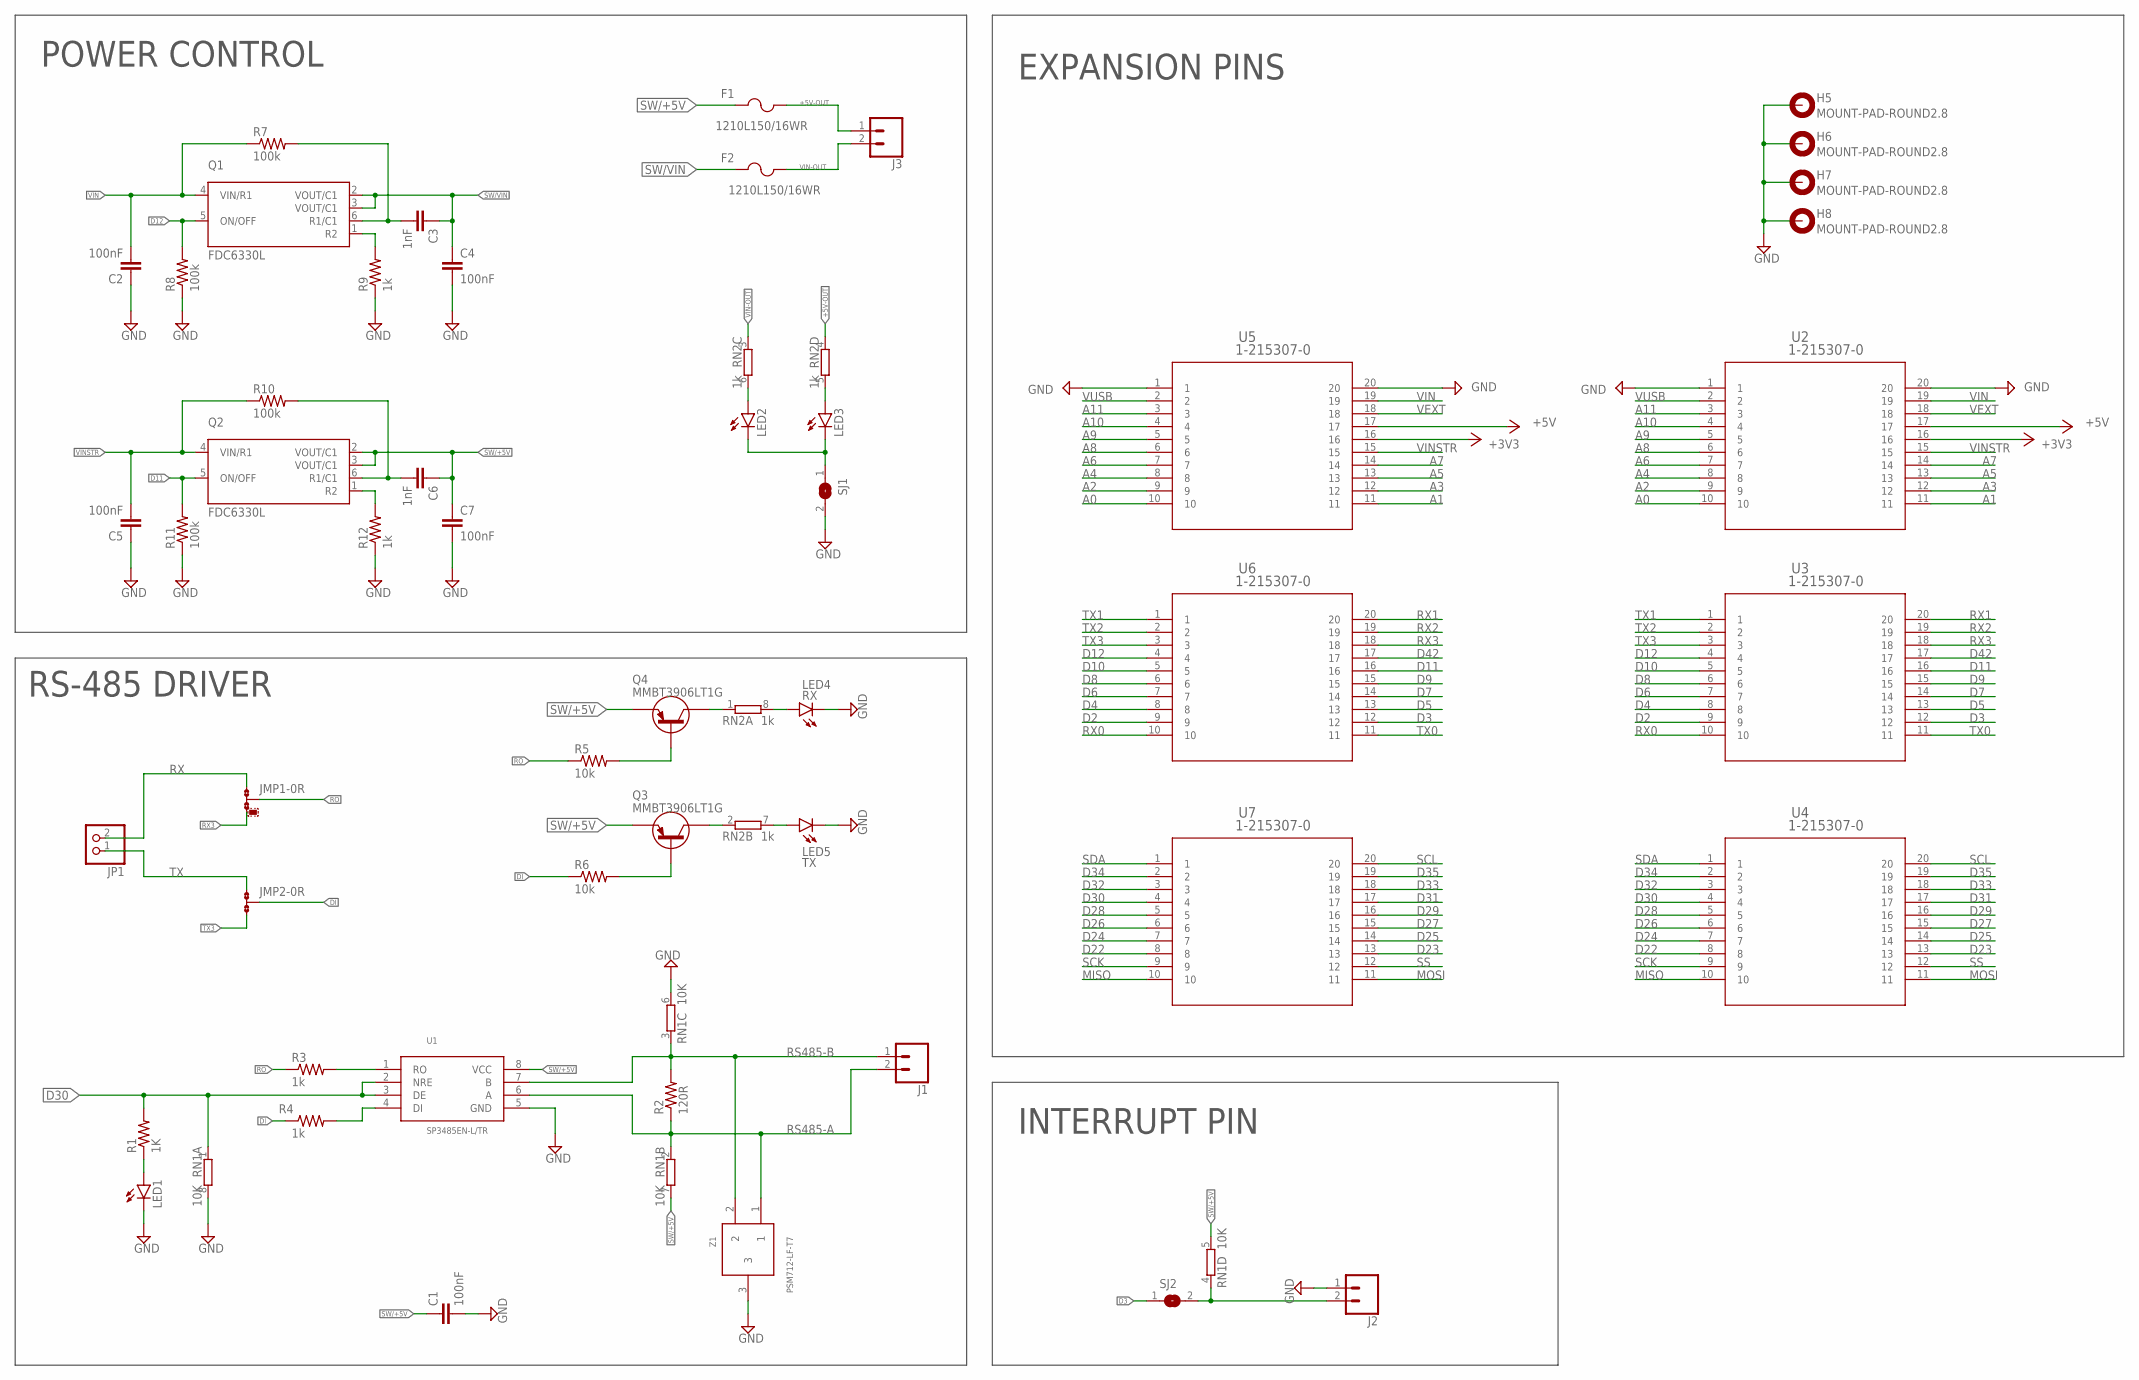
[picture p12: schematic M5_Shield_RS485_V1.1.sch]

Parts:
C1: 100nF; C0603K
C2, C4, C5, C7: 100nF; C0603
C3, C6: 1nF; C0603
F1, F2: 1210L150/16WR; 1210LSERIES
H5, H6, H7, H8: MOUNT-PAD-ROUND2.8; 2,8-PAD
J1, J2, J3: CONN_023.5MM; SCREWTERMINAL-3.5MM-2
JMP1, JMP2: 0R-JUMPA; A0R-JMP
JP1: PINHD-1X2; 1X02
LED1: LEDCHIPLED_0603; CHIPLED_0603
LED2, LED3: LEDCHIP-LED0603; CHIP-LED0603
LED4: RX; CHIP-LED0603
LED5: TX; CHIP-LED0603
Q1, Q2: FDC6330L; SOT95P280X110-6N
Q3, Q4: MMBT3906LT1G; SOT23
R1: 1K; R0603
R2: 120R; R0603
R3, R4, R9, R12: 1k; R0603
R5, R6: 10k; R0603
R7, R8, R10, R11: 100k; R0603
RN1: 10K; 0603-ARV
RN2: 1k; 0603-ARV
SJ1, SJ2: SJ
U1: SP3485EN-L/TR
U2, U3, U4, U5, U6, U7: 1-215307-0
Z1: PSM712-LF-T7; SOT23

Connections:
+3V3: U2.16, U5.16
+5V: U2.17, U5.17
+5V-OUT: F1.2, J3.1, RN2.4 (1)
A0: U2.10, U5.10
A1: U2.11, U5.11
A2: U2.9, U5.9
A3: U2.12, U5.12
A4: U2.8, U5.8
A5: U2.13, U5.13
A6: U2.7, U5.7
A7: U2.14, U5.14
A8: U2.6, U5.6
A9: U2.5, U5.5
A10: U2.4, U5.4
A11: U2.3, U5.3
D2: U3.9, U6.9
D3: SJ2.1, U3.12, U6.12
D4: U3.8, U6.8
D5: U3.13, U6.13
D6: U3.7, U6.7
D7: U3.14, U6.14
D8: U3.6, U6.6
D9: U3.15, U6.15
D10: U3.5, U6.5
D11: Q2.5 (ON/OFF), R11.2, U3.16, U6.16
D12: Q1.5 (ON/OFF), R8.2, U3.4, U6.4
D22: U4.8, U7.8
D23: U4.13, U7.13
D24: U4.7, U7.7
D25: U4.14, U7.14
D26: U4.6, U7.6
D27: U4.15, U7.15
D28: U4.5, U7.5
D29: U4.16, U7.16
D30: R1.2, RN1.1, U1.2 (NRE), U1.3 (DE), U4.4, U7.4
D31: U4.17, U7.17
D32: U4.3, U7.3
D33: U4.18, U7.18
D34: U4.2, U7.2
D35: U4.19, U7.19
D42: U3.17, U6.17
DI: JMP2.2, R4.1, R6.1
GND: C1.2, C2.1, C4.2, C5.1, C7.2, H5.B2,8, H6.B2,8, H7.B2,8, H8.B2,8, J2.1, LED1.C, LED4.C, LED5.C, R8.1, R9.1, R11.1, R12.1, RN1.6 (2), RN1.8 (2), SJ1.2, U1.5 (GND), U2.1, U2.20, U5.1, U5.20, Z1.3
MISO: U4.10, U7.10
MOSI: U4.11, U7.11
unnamed: LED1.A, R1.1
unnamed: R3.2, U1.1 (RO)
unnamed: J2.2, RN1.4 (1), SJ2.2
unnamed: Q4.3 (C), RN2.1
unnamed: R4.2, U1.4 (DI)
unnamed: LED3.A, RN2.5 (2)
unnamed: LED2.C, LED3.C, SJ1.1
unnamed: LED2.A, RN2.6 (2)
unnamed: Q3.3 (C), RN2.2 (1)
unnamed: LED4.A, RN2.8 (2)
unnamed: C6.2, Q2.6 (R1/C1), R10.2
unnamed: Q1.1 (R2), R9.2
unnamed: LED5.A, RN2.7 (2)
unnamed: Q4.1 (B), R5.2
unnamed: C3.2, Q1.6 (R1/C1), R7.2
unnamed: Q3.1 (B), R6.2
unnamed: Q2.1 (R2), R12.2
RO: JMP1.2, R3.1, R5.1
RS485-A: J1.2, R2.1, RN1.2 (1), U1.6 (A), Z1.1
RS485-B: J1.1, R2.2, RN1.3 (1), U1.7 (B), Z1.2
RX: JMP1.1, JP1.2
RX0: U3.10, U6.10
RX1: U3.20, U6.20
RX2: U3.19, U6.19
RX3: JMP1.3, U3.18, U6.18
SCK: U4.9, U7.9
SCL: U4.20, U7.20
SDA: U4.1, U7.1
SS: U4.12, U7.12
SW/+5V: C1.1, C6.1, C7.1, F1.1, Q2.2 (VOUT/C1), Q2.3 (VOUT/C1), Q3.2 (E), Q4.2 (E), RN1.5 (2), RN1.7 (2), U1.8 (VCC)
SW/VIN: C3.1, C4.1, F2.1, Q1.2 (VOUT/C1), Q1.3 (VOUT/C1)
TX: JMP2.1, JP1.1
TX0: U3.11, U6.11
TX1: U3.1, U6.1
TX2: U3.2, U6.2
TX3: JMP2.3, U3.3, U6.3
VEXT: U2.18, U5.18
VIN: C2.2, Q1.4 (VIN/R1), R7.1, U2.19, U5.19
VIN-OUT: F2.2, J3.2, RN2.3 (1)
VINSTR: C5.2, Q2.4 (VIN/R1), R10.1, U2.15, U5.15
VUSB: U2.2, U5.2

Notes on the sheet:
RS-485 DRIVER
POWER CONTROL
EXPANSION PINS
INTERRUPT PIN

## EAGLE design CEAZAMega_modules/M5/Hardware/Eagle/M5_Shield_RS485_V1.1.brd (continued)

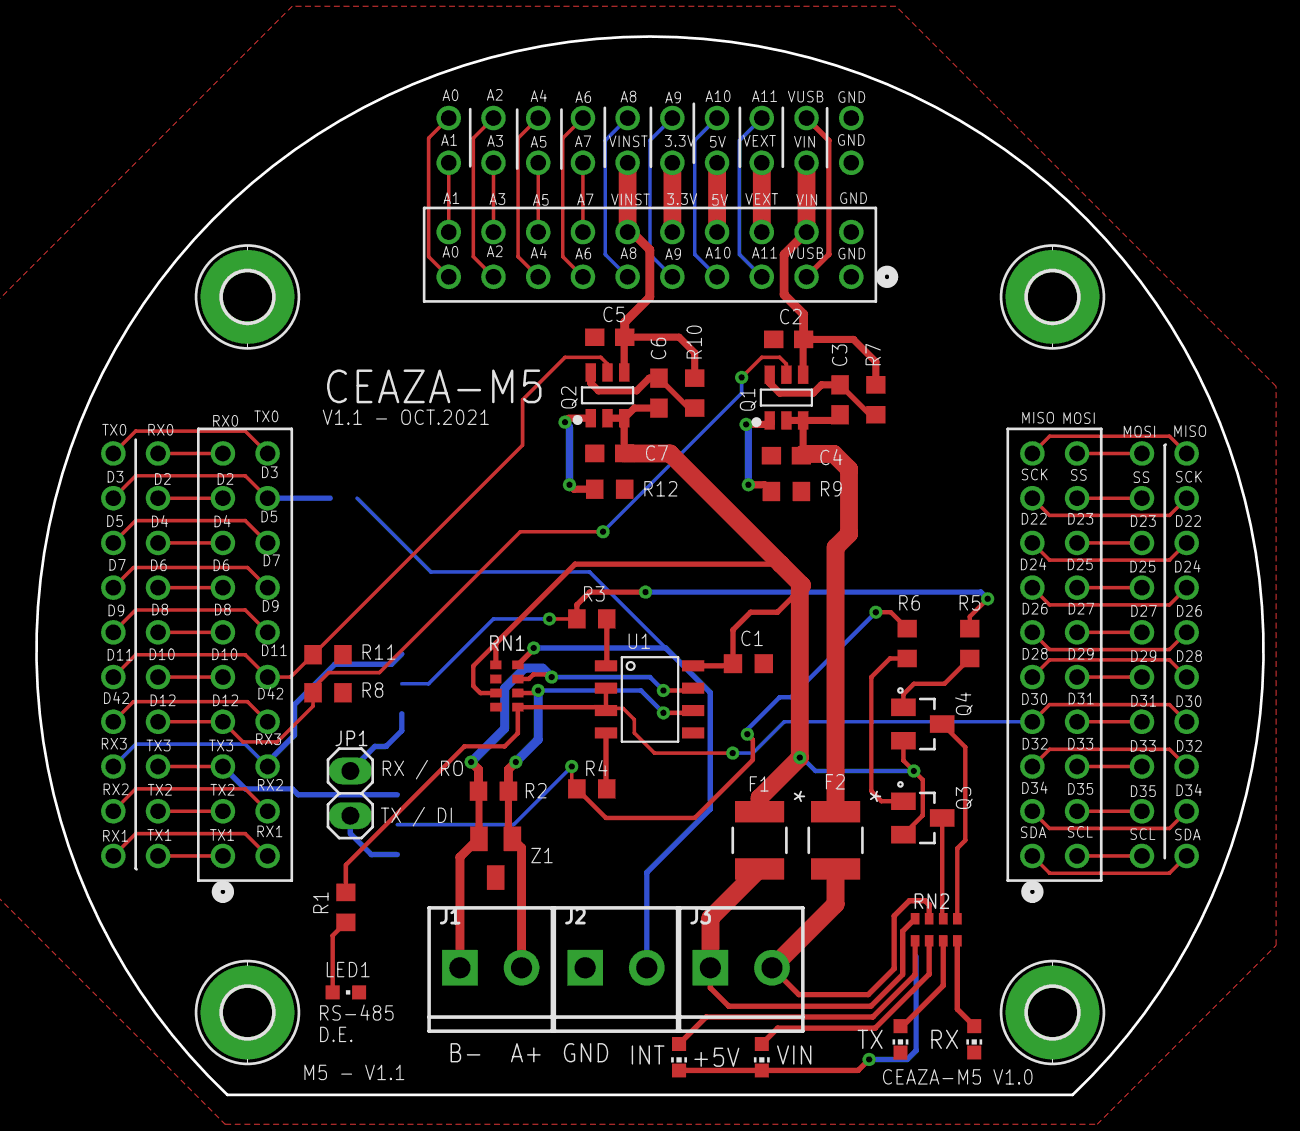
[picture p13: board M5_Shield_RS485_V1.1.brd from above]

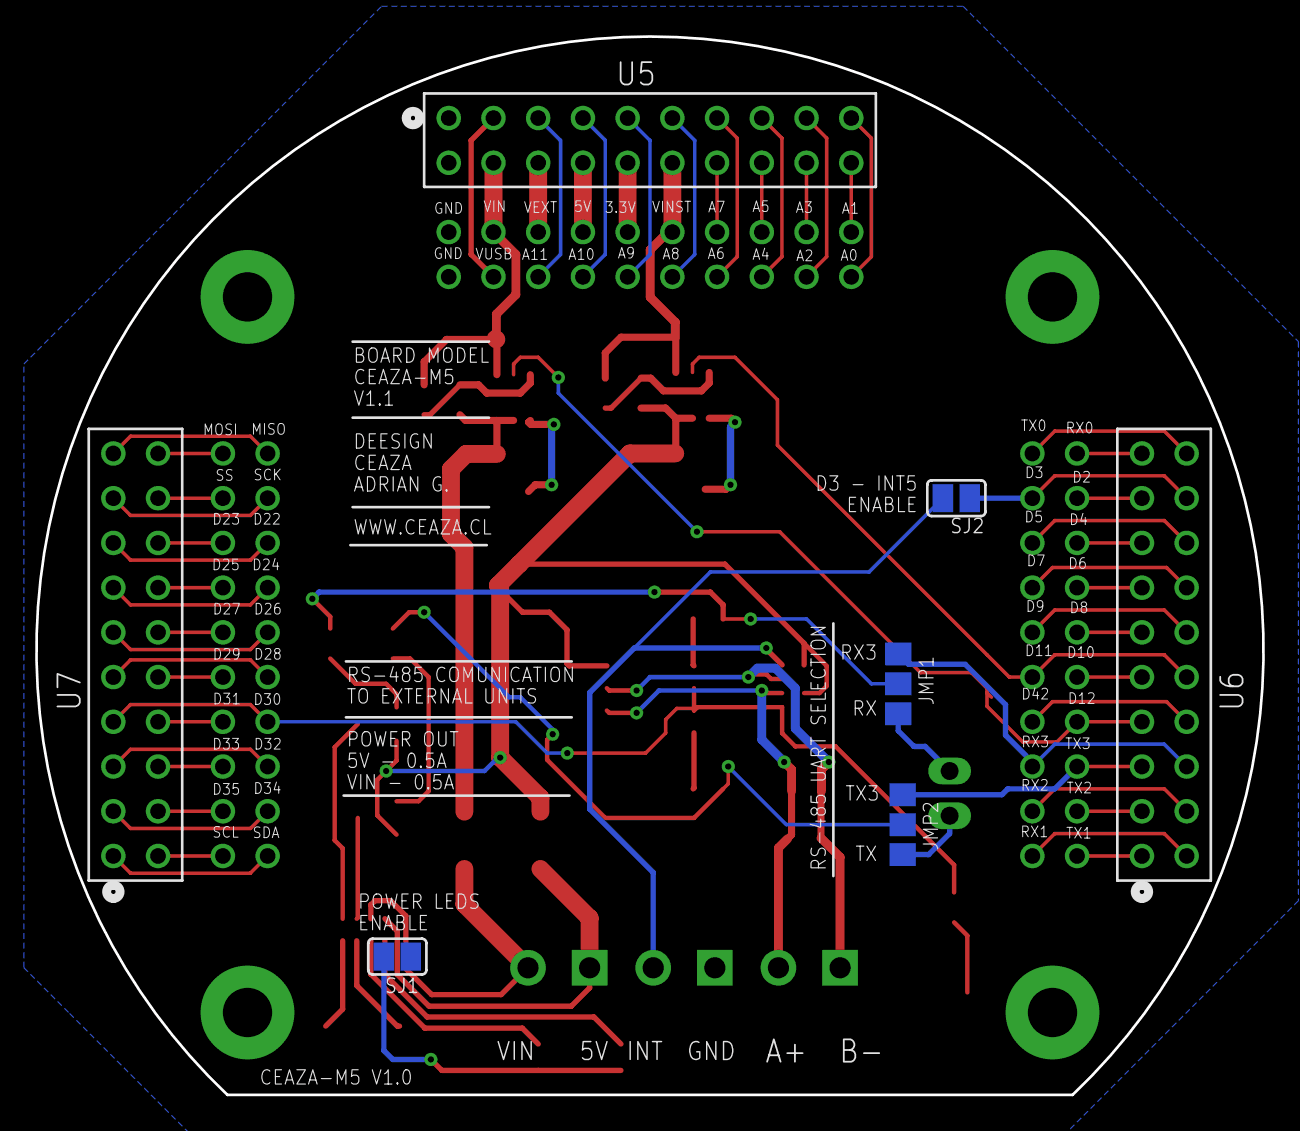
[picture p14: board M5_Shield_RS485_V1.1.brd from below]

Board: 2 copper layers, 69.7 x 60.1 mm, 52 parts (7 on the bottom side), 86 nets.

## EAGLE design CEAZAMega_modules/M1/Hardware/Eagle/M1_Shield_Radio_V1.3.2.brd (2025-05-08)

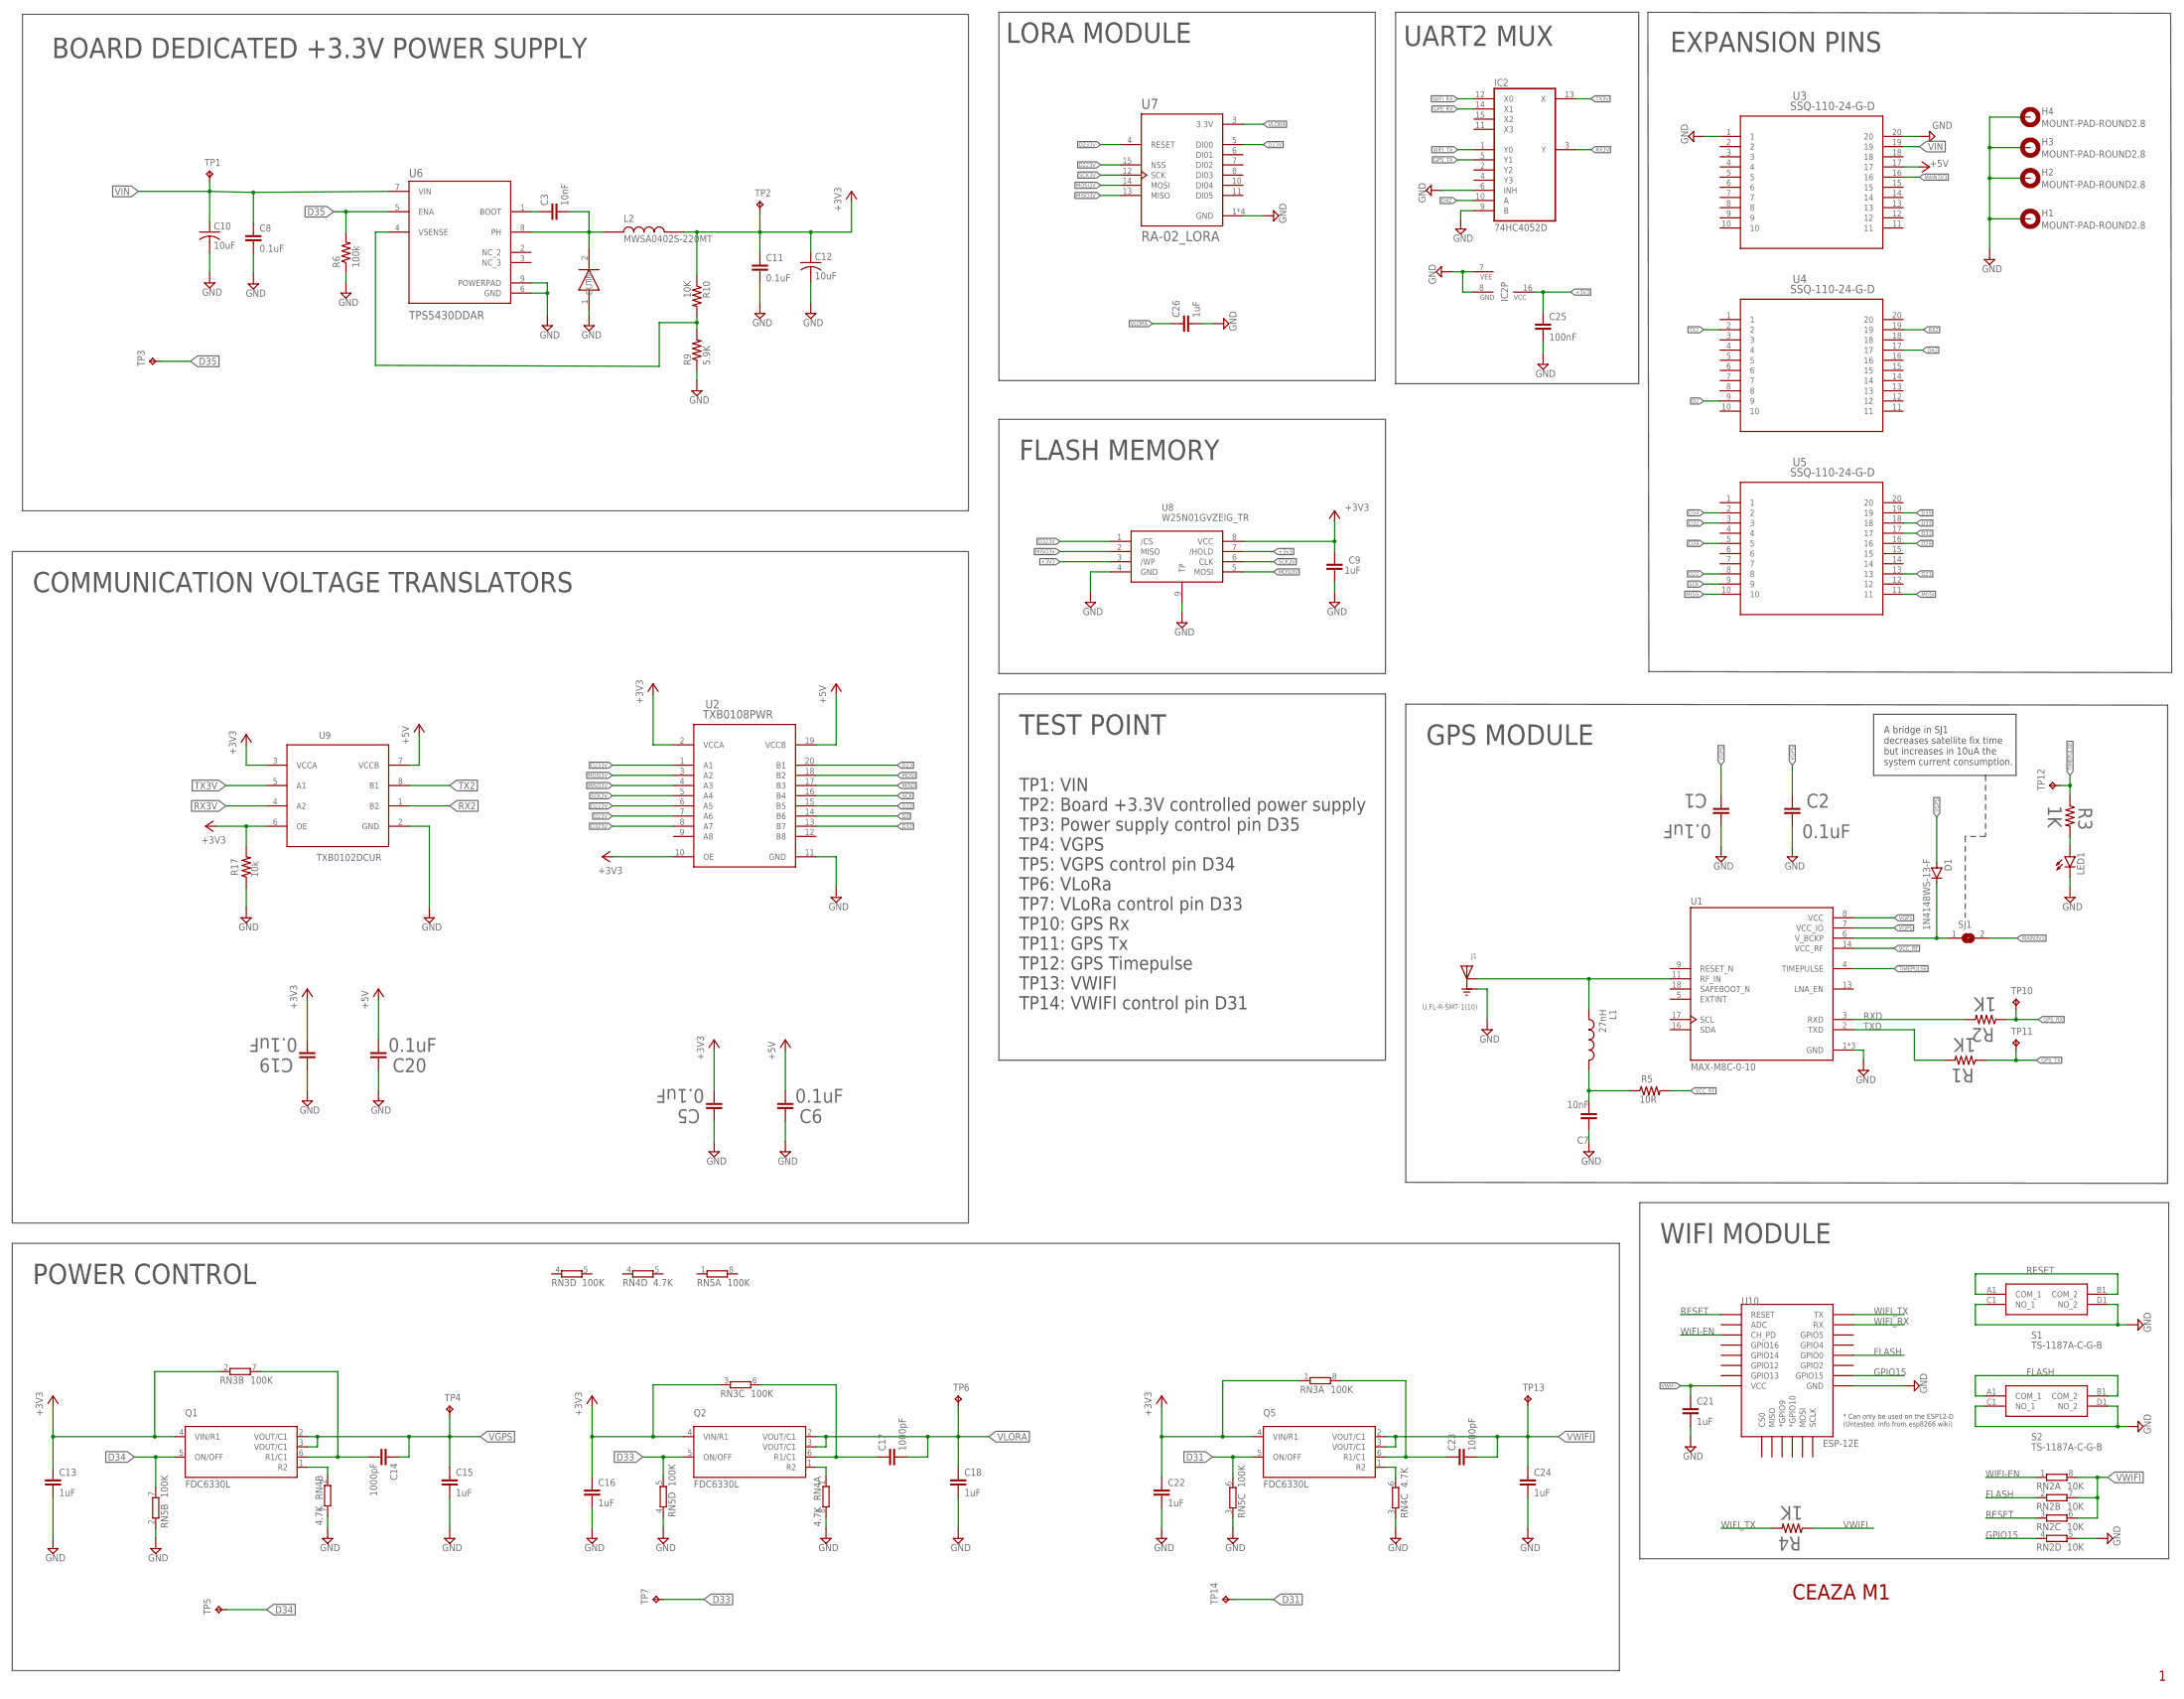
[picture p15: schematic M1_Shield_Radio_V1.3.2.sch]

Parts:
C1, C2, C5, C6, C8, C11, C19, C20: 0.1uF; C0603K
C3, C7: 10nF; C0603K
C9, C13, C15, C16, C18, C21, C22, C24, C26: 1uF; C0603K
C10, C12: 10uF; C0603K
C14, C17, C23: 1000pF; C0603K
C25: 100nF; C0603K
D1: 1N4148WS-13-F; SOD323-W
H1, H2, H3, H4: MOUNT-PAD-ROUND2.8; 2,8-PAD
IC2: 74HC4052D; SO16
J1: U.FL-R-SMT-1(10); HRS_U.FL-R-SMT-1(10)
L1: 27nH; INDC1005X55N
L2: MWSA0402S-220MT
LED1: LEDCHIP-LED0805; CHIP-LED0805
Q1, Q2, Q5: FDC6330L; SOT95P280X110-6N
R1, R2, R3, R4: 1K; R0603
R5: 10R; R0603
R6: 100k; R0603
R9: 5.9K; R0603
R10: 10K; R0603
R17: 10k; R0603
RN2: 10K; 0603-ARV
RN3, RN5: 100K; 0603-ARV
RN4: 4.7K; 0603-ARV
S1, S2: TS-1187A-C-G-B; TS1187ACGB
SJ1: SJ
TP1, TP2, TP3, TP4, TP5, TP6, TP7, TP10, TP11, TP12, TP13, TP14: TPB1,27; B1,27
U1: MAX-M8C-0-10; XCVR_MAX-M8C-0-10
U2: TXB0108PWR; PW0020A_N
U3, U4, U5: SSQ-110-24-G-D; 1-215307-0
U6: TPS5430DDAR; CONV_TPS5430DDAR
U7: RA-02_LORA; MODULE_RA-02_LORA
U8: W25N01GVZEIG_TR; W25N01GVZEIGTR
U9: TXB0102DCUR; DCU0008A_L
U10: ESP-12E; ESP12E-SMD
U$1: SMA-SS34

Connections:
+3V3: C5.2, C9.1, C11.1, C12.1, C13.1, C16.1, C19.2, C22.1, C25.1, IC2.16 (VCC), L2.P$2, Q1.4 (VIN/R1), Q2.4 (VIN/R1), Q5.4 (VIN/R1), R10.1, R17.2, RN3.1, RN3.2 (1), RN3.3 (1), TP2.TP, U2.2 (VCCA), U2.10 (OE), U8.3 (/WP), U8.7 (/HOLD), U8.8 (VCC), U9.3 (VCCA), U9.6 (OE)
+5V: C6.2, C20.2, U2.19 (VCCB), U3.17, U9.7 (VCCB)
D2: U2.14 (B6), U4.9
D22: U2.15 (B5), U5.8
D23: U2.20 (B1), U5.13
D23V: U2.7 (A6), U7.5 (DI00)
D28: U5.5
D29: U5.16
D31: Q5.5 (ON/OFF), RN5.6 (2), TP14.TP, U5.17
D32: U2.13 (B7), U5.3
D33: Q2.5 (ON/OFF), RN5.5 (2), TP7.TP, U5.18
D34: Q1.5 (ON/OFF), RN5.7 (2), TP5.TP, U5.2
D35: R6.2, TP3.TP, U5.19, U6.5 (ENA)
D42: IC2.10 (A), U4.17
D223V: U2.6 (A5), U7.15 (NSS)
D233V: U2.1 (A1), U7.4 (RESET)
D323V: U2.8 (A7), U8.1 (/CS)
FLASH: RN2.2 (1), S2.A1 (COM_1), S2.B1 (COM_2), U10.GPIO0
GND: C1.1, C2.1, C5.1, C6.1, C7.1, C8.2, C9.2, C10.2, C11.2, C12.2, C13.2, C15.2, C16.2, C18.2, C19.1, C20.1, C21.2, C22.2, C24.2, C25.2, C26.2, H1.B2,8, H2.B2,8, H3.B2,8, H4.B2,8, IC2.6 (INH), IC2.7 (VEE), IC2.8 (GND), IC2.9 (B), J1.1 (GND), J1.3 (GND), LED1.C, R6.1, R9.1, R17.1, RN2.5 (2), RN4.3 (1), RN4.7 (2), RN4.8 (2), RN5.2 (1), RN5.3 (1), RN5.4 (1), S1.C1 (NO_1), S1.D1 (NO_2), S2.C1 (NO_1), S2.D1 (NO_2), U1.1 (GND), U1.10 (GND), U1.12 (GND), U2.11 (GND), U3.1, U3.20, U6.6 (GND), U6.9 (POWERPAD), U7.1 (GND), U7.2 (GND), U7.9 (GND), U7.16 (GND), U8.4 (GND), U8.9 (TP), U9.2 (GND), U10.GND, U$1.1 (IN)
GPIO15: RN2.4 (1), U10.GPIO15
GPS_RX: IC2.14 (X1), R2.1, TP10.TP
GPS_TX: IC2.5 (Y1), R1.1, TP11.TP
MAIN3V3: SJ1.2, U3.16
MISO: U2.17 (B3), U5.10
MISO3V: U2.4 (A3), U7.13 (MISO), U8.2 (MISO)
MOSI: U2.18 (B2), U5.11
MOSI3V: U2.3 (A2), U7.14 (MOSI), U8.5 (MOSI)
unnamed: Q5.1 (R2), RN4.6 (2)
unnamed: LED1.A, R3.2
unnamed: J1.2 (SIG), L1.1, U1.11 (RF_IN)
unnamed: C7.2, L1.2, R5.1
unnamed: C3.1, U6.1 (BOOT)
unnamed: C14.2, Q1.6 (R1/C1), RN3.7 (2)
unnamed: C23.1, Q5.6 (R1/C1), RN3.8 (2)
unnamed: Q1.1 (R2), RN4.2 (1)
unnamed: Q2.1 (R2), RN4.1
unnamed: C17.1, Q2.6 (R1/C1), RN3.6 (2)
unnamed: D1.C, SJ1.1, U1.6 (V_BCKP)
unnamed: C3.2, L2.P$1, U6.8 (PH), U$1.2 (OUT)
RESET: RN2.3 (1), S1.A1 (COM_1), S1.B1 (COM_2), U10.RESET
RX2: U4.19, U9.1 (B2)
RX3V: IC2.3 (Y), U9.4 (A2)
RXD: R2.2, U1.3 (RXD)
SCK: U2.16 (B4), U5.9
SCK3V: U2.5 (A4), U7.12 (SCK), U8.6 (CLK)
TIMEPULSE: R3.1, TP12.TP, U1.4 (TIMEPULSE)
TX2: U4.2, U9.8 (B1)
TX3V: IC2.13 (X), U9.5 (A1)
TXD: R1.2, U1.2 (TXD)
VCC_RF: R5.2, U1.14 (VCC_RF)
VFB: R9.2, R10.2, U6.4 (VSENSE)
VGPS: C1.2, C2.2, C14.1, C15.1, D1.A, Q1.2 (VOUT/C1), Q1.3 (VOUT/C1), TP4.TP, U1.7 (VCC_IO), U1.8 (VCC)
VIN: C8.1, C10.1, TP1.TP, U3.19, U6.7 (VIN)
VLORA: C17.2, C18.1, C26.1, Q2.2 (VOUT/C1), Q2.3 (VOUT/C1), TP6.TP, U7.3 (3.3V)
VWIFI: C21.1, C23.2, C24.1, Q5.2 (VOUT/C1), Q5.3 (VOUT/C1), R4.1, RN2.6 (2), RN2.7 (2), RN2.8 (2), TP13.TP, U10.VCC
WIFI-EN: RN2.1, U10.CH_PD
WIFI_RX: IC2.12 (X0), U10.RXD0 (RX)
WIFI_TX: IC2.1 (Y0), R4.2, U10.TXD0 (TX)

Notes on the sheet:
BOARD DEDICATED +3.3V POWER SUPPLY
LORA MODULE
FLASH MEMORY
POWER CONTROL
GPS MODULE
COMMUNICATION VOLTAGE TRANSLATORS
EXPANSION PINS
TP1: VIN TP2: Board +3.3V controlled power supply TP3: Power supply control pin D35 TP4: VGPS TP5: VGPS control pin D34 TP6: VLoRa TP7: VLoRa control pin D33 TP10: GPS Rx TP11: GPS Tx TP12: GPS Timepulse TP13: VWIFI TP14: VWIFI control pin D31
TEST POINT
UART2 MUX
WIFI MODULE
A bridge in SJ1 decreases satellite fix time but increases in 10uA the system current consumption.
CEAZA M1

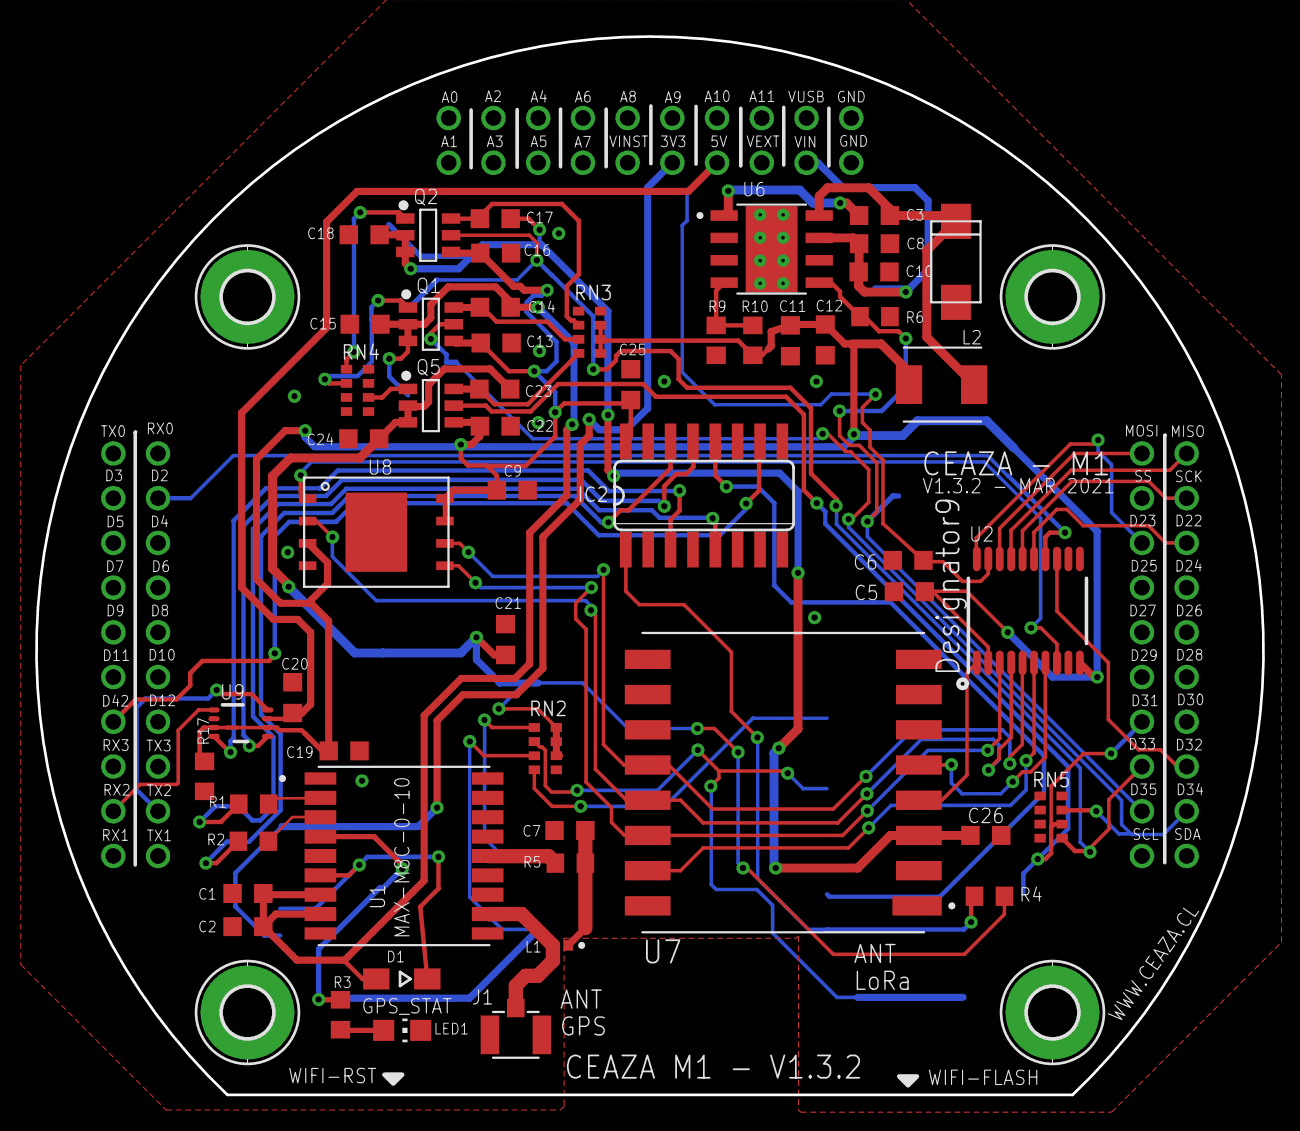
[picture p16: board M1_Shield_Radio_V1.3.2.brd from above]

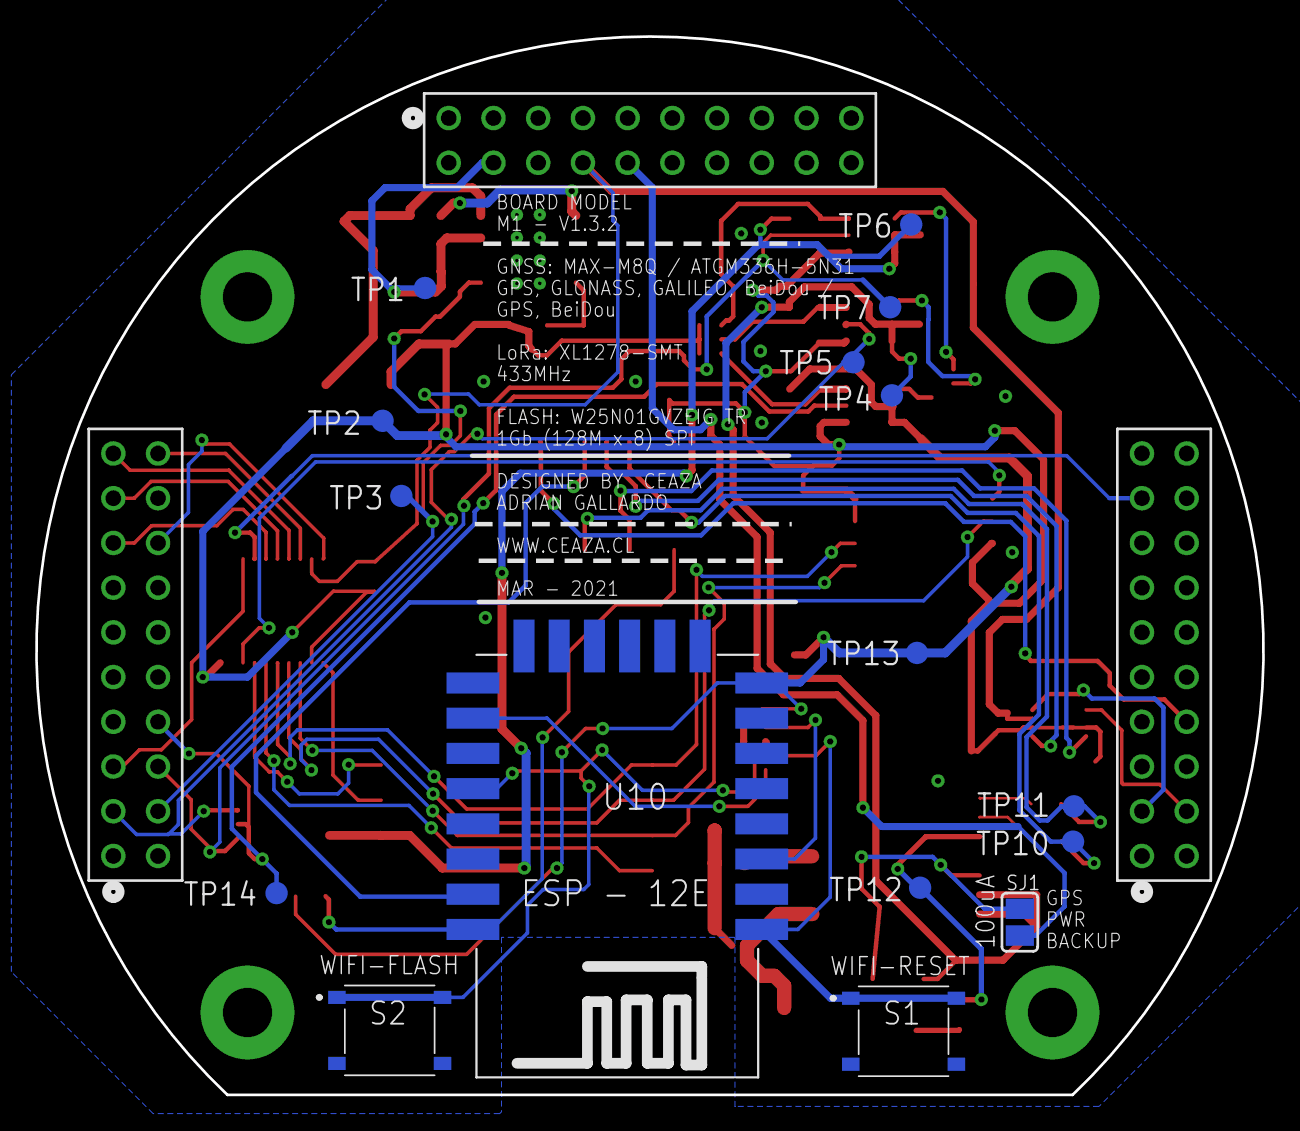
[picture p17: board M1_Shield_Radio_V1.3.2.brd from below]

Board: 2 copper layers, 69.7 x 60.1 mm, 77 parts (19 on the bottom side), 56 nets.

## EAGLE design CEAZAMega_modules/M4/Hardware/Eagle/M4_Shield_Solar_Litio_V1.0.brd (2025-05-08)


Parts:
C1: 4.7uF; C0603K
C2, C4, C9: 1uF; C0603K
C3: 3pf; C0603K
C5, C10: 10uF; 153CLV-0505
C6, C8: 100nF; C0603K
C7: 220nF; C0603K
C20: 1nF; C0603K
D1, D2, D3: SMA-SS34
H5, H6, H7, H8: MOUNT-PAD-ROUND2.8; 2,8-PAD
J3, J4: S2B-PH-K-S(LF)(SN); JST_S2B-PH-K-S(LF)(SN)
JP2: PINHD-1X3/90; 1X03/90
L1: MWSA0503-100MT 10UH; MWSA0503
L2: SWRB1204S-470MTSMD; SWRB1204S-470MT
LED1: GREEN; CHIPLED_0603
LED2: RED; CHIPLED_0603
Q1: AO3407A; SOT95P280X125-3N
R1, R10: 1M; R0603
R2: 200k; R0603
R3: 0.12; R0805
R4: 2K; R0603
R15: 120; R0603
R16: 1.5M; R0603
R17: 167k; R0603
R18: 374k; R0603
R19: 510K; R0603
R20: 1K; R0603
TP3, TP7, TP8, TP9, TP10: TPB1,27; B1,27
U1: TPS61040DBVR; DBV0005A
U2: CN3791
U3, U4, U5, U6, U7, U8: 1-215307-0

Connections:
3.7V-BAT: C1.1, C4.2, C5.+, J4.1, L1.1, R3.2, R20.1, TP10.TP, U1.4 (EN), U1.5 (VIN), U2.7 (BAT)
6V/12V-CELL: C6.1, C8.1, C9.2, C10.+, J3.1, Q1.2 (S), R4.2, R10.1, R16.2, TP9.TP, U2.9 (VCC)
6VMPPT: JP2.3, R18.2
12VMPPT: JP2.1, R17.2, R18.1
+3V3: U3.16, U4.16
+5V: U3.17, U4.17
A0: U3.10, U4.10
A1: U3.11, U4.11
A2: U3.9, U4.9
A3: U3.12, U4.12
A4: U3.8, U4.8
A5: U3.13, U4.13
A6: U3.7, U4.7
A7: U3.14, U4.14
A8: U3.6, U4.6
A9: U3.5, U4.5
A10: R20.2, TP7.TP, U3.4, U4.4
A11: C20.1, R10.2, R19.1, TP3.TP, U3.3, U4.3
CHRG: LED2.C, U2.3 (/CHRG)
D2: U5.9, U7.9
D3: U5.12, U7.12
D4: U5.8, U7.8
D5: U5.13, U7.13
D6: U5.7, U7.7
D7: U5.14, U7.14
D8: U5.6, U7.6
D9: U5.15, U7.15
D10: U5.5, U7.5
D11: U5.16, U7.16
D12: U5.4, U7.4
D22: U6.8, U8.8
D23: U6.13, U8.13
D24: U6.7, U8.7
D25: U6.14, U8.14
D26: U6.6, U8.6
D27: U6.15, U8.15
D28: U6.5, U8.5
D29: U6.16, U8.16
D30: U6.4, U8.4
D31: U6.17, U8.17
D32: U6.3, U8.3
D33: U6.18, U8.18
D34: U6.2, U8.2
D35: U6.19, U8.19
D42: U5.17, U7.17
DONE: LED1.C, U2.4 (/DONE)
GND: C1.2, C2.2, C4.1, C5.-, C6.2, C7.2, C9.1, C10.-, C20.2, D3.1 (IN), H5.B2,8, H6.B2,8, H7.B2,8, H8.B2,8, J3.2, J4.2, R2.1, R17.1, R19.2, U1.2 (GND), U2.2 (GND), U3.1, U3.20, U4.1, U4.20
MISO: U6.10, U8.10
MOSI: U6.11, U8.11
MPPT: JP2.2, R16.1, U2.6 (MPPT)
unnamed: D1.1 (IN), L1.2, U1.1 (SW)
unnamed: D2.2 (OUT), D3.2 (OUT), L2.1
unnamed: C3.2, R1.1, R2.2, U1.3 (FB)
unnamed: L2.2, R3.1, U2.8 (CSP)
unnamed: R15.2, U2.5 (COM)
unnamed: D2.1 (IN), Q1.3 (D)
unnamed: Q1.1 (G), U2.10 (DRV)
unnamed: LED1.A, LED2.A, R4.1
unnamed: C7.1, R15.1
unnamed: C8.2, U2.1 (VG)
RX0: U5.10, U7.10
RX1: U5.20, U7.20
RX2: U5.19, U7.19
RX3: U5.18, U7.18
SCK: U6.9, U8.9
SCL: U6.20, U8.20
SDA: U6.1, U8.1
SS: U6.12, U8.12
TX0: U5.11, U7.11
TX1: U5.1, U7.1
TX2: U5.2, U7.2
TX3: U5.3, U7.3
VEXT: U3.18, U4.18
VIN: C2.1, C3.1, D1.2 (OUT), R1.2, TP8.TP, U3.19, U4.19
VINSTR: U3.15, U4.15
VUSB: U3.2, U4.2

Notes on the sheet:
3.7V Li/Po BATTERY CHARGER
Solar cell voltage selector: 6V / 12V
3.7V TO 7.4V DC/DC CONVERTER
POWER VOLTMETERS
I/O TERMINAL
PROTOTIPOS



Board: 2 copper layers, 69.7 x 60.1 mm, 50 parts (9 on the bottom side), 76 nets.

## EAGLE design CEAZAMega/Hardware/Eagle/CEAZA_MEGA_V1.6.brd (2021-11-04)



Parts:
BATT01: 2032; KZH20SMD
C1: 22p; C0603-ROUND
C2, C3, C4, C5, C6, C7, C8, C9, C10, C11, C12, C14, C15, C16, C17, C22, C25, C26, C27, C28, C29: 100nF; C0603-ROUND
C13, C18, C19, C20: 1uF; C0603-ROUND
C21: 4.7uF; C0603-ROUND
C23: 33pF; C0603-ROUND
C24: 10uF; C0603-ROUND
C30, C31: 22pF; C0603-ROUND
D1: M7; SMB
D2: Green; CHIPLED_0805
D3: 1N4148W; SOD-123_MINI-SMA
D4: Red; CHIPLED_0805
F1: MF-MSMF050-2 500mA; L1812
FD1, FD2, FD3, FD4: FIDUCIALMOUNT; FIDUCIA-MOUNT
H5, H6, H7, H8: MOUNT-PAD-ROUND2.8; 2,8-PAD
IC3: ATMEGA2560-15AU; TQFP100
ICSP: ICSP; 2X03
J1: MEM2051-00-195-00-A_REVC; GCT_MEM2051-00-195-00-A_REVC
J2, J3, J4, J5: B3B-PH-K-S(LF)(SN); CONN_B3B-PH-K-S(LF)(SN)_JST
J6: B2B-PH-K-S(LF)(SN); JST_B2B-PH-K-S(LF)(SN)
L: Yellow; CHIPLED_0805
L1: MH2029-300Y; 0805
L2: MWSA0503-4R7MT; MWSA0503
L3: 10uH; INDC1608X90N
Q1, Q2, Q3: AO3407A; SOT95P280X125-3N
R1, R8, R13: 1M; R0603
R2: 4.7k; R0603
R3: 22K; R0603
R4: 120K; R0603
R5: 470K; R0603
R6: 1k; R0603
R7, R9: 10K; R0603
R10, R11: 22R; R0603
R12: 10k; R0603
R14: 100K; R0603
R15: 270K; R0603
RN1: 10k; CAY16
RN3: 4.7K; CAY16
RN4: 1K; CAY16
RN6: 1K; 0603-ARV
RX: Blue; CHIPLED_0805
S1: TS-1187A-C-G-B; TS1187ACGB
TR1: R-EU_R0603; R0603
TX: Orange; CHIPLED_0805
U1: CP2104-F03-GM; QFN50P400X400X80-25N
U2: DS3231MZ+; SOIC127P600X175-8N
U3: TXB0104PWR; PW14
U4, U5, U6: 1-215307-0
U7: MP2451DT-LF-Z; SOT95P275X110-6N
U8: SP3232EEY-LT/TLSMD; SOP65P640X120-16N
U9: CN305; SOT23-6
U$1: MCP1702T-5002E/CB; SOT95P255X145-3N
U$2: MCP1700T-3302E/TT; SOT95P237X112-3N
U$3: SMA-SS34
X1: MINI-USB-SCHIELD-32005-201; 32005-201
Y1: X322516MLB4SI
Z1: PSM712-LF-T7; SOT23

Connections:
+3V3: C13.2, Q2.2 (S), U4.16, U$2.2 (VOUT)
+5V: C4.1, C5.1, C6.1, C17.2, C18.2, C19.2, D3.C, IC3.10 (VCC), IC3.31 (VCC1), IC3.61 (VCC2), IC3.80 (VCC3), ICSP.2, L3.2, Q3.2 (S), R2.2, R8.2, R9.2, RN1.6 (2), RN1.7 (2), U3.14 (VCCB), U4.17, U9.4 (VCC), U$1.2 (VOUT), U$2.3 (VIN)
A0: IC3.97 ((ADC0)PF0), U4.10
A1: IC3.96 ((ADC1)PF1), U4.11
A2: IC3.95 ((ADC2)PF2), U4.9
A3: IC3.94 ((ADC3)PF3), U4.12
A4: IC3.93 ((ADC4/TCK)PF4), U4.8
A5: IC3.92 ((ADC5/TMS)PF5), U4.13
A6: IC3.91 ((ADC6/TDO)PF6), U4.7
A7: IC3.90 ((ADC7/TDI)PF7), U4.14
A8: IC3.89 (PK0(ADC8/PCINT16)), U4.6
A9: IC3.88 (PK1(ADC9/PCINT17)), U4.5
A10: IC3.87 (PK2(ADC10/PCINT18)), U4.4
A11: IC3.86 (PK3(ADC11/PCINT19)), U4.3
A12: C12.1, IC3.85 (PK4(ADC12/PCINT20)), R12.2, TR1.1
A13: IC3.84 (PK5(ADC13/PCINT21))
A14: IC3.83 (PK6(ADC14/PCINT22)), R1.2, R5.1
A15: IC3.82 (PK7(ADC15/PCINT23))
AREF: C3.1, IC3.98 (AREF)
AVCC: C16.1, IC3.100 (AVCC), L3.1
D2: IC3.6 ((OC3B/INT4)PE4), U5.9
D3: IC3.7 ((OC3C/INT5)PE5), U5.12
D4: IC3.1 ((OC0B)PG5), U5.8
D5: IC3.5 ((OC3A/AIN1)PE3), U5.13
D6: IC3.15 (PH3(OC4A)), U5.7
D7: IC3.16 (PH4(OC4B)), U5.14
D8: IC3.17 (PH5(OC4C)), U5.6
D9: IC3.18 (PH6(OC2B)), U5.15
D10: IC3.23 ((OC2A/PCINT4)PB4), U5.5
D11: IC3.24 ((OC1A/PCINT5)PB5), U5.16
D12: IC3.25 ((OC1B/PCINT6)PB6), U5.4
D13: IC3.26 ((OC0A/OC1C/PCINT7)PB7), RN3.7 (2)
D22: IC3.78 ((AD0)PA0), U6.8
D23: IC3.77 ((AD1)PA1), U6.13
D24: IC3.76 ((AD2)PA2), U6.7
D25: IC3.75 ((AD3)PA3), U6.14
D26: IC3.74 ((AD4)PA4), U6.6
D27: IC3.73 ((AD5)PA5), U6.15
D28: IC3.72 ((AD6)PA6), U6.5
D29: IC3.71 ((AD7)PA7), U6.16
D30: IC3.60 ((A15)PC7), U6.4
D31: IC3.59 ((A14)PC6), U6.17
D32: IC3.58 ((A13)PC5), U6.3
D33: IC3.57 ((A12)PC4), U6.18
D34: IC3.56 ((A11)PC3), U6.2
D35: IC3.55 ((A10)PC2), U6.19
D36: C14.1, IC3.54 ((A9)PC1), U2.2 (VCC)
D37: IC3.53 ((A8)PC0)
D38: IC3.50 ((T0)PD7), J3.2, R2.1
D39: IC3.70 ((ALE)PG2), J4.2, R6.2
D40: IC3.52 ((RD)PG1), RN6.1, RN6.3 (1)
D41: IC3.51 ((WR)PG0), RN6.2 (1), RN6.4 (1)
D42: IC3.42 (PL7), U5.17
D43: IC3.41 (PL6), RN1.1
D44: IC3.40 (PL5(OC5C)), U7.4 (EN)
D45: IC3.39 (PL4(OC5B))
D46: IC3.38 (PL3(OC5A)), R7.1
D47: IC3.37 (PL2(T5))
D48: C11.2, IC3.36 (PL1(ICP5)), J3.1
D49: C25.1, IC3.35 (PL0(ICP4)), U8.16 (VCC)
D+: R11.1, X1.3, Z1.2
D-: R10.1, X1.2, Z1.1
DTR: C7.1, RN3.5 (2), U1.23 (!DTR)
GND: BATT01.-, C1.2, C2.2, C3.2, C4.2, C5.2, C6.2, C8.2, C9.2, C10.2, C11.1, C12.2, C13.1, C14.2, C15.2, C16.2, C17.1, C18.1, C19.1, C20.1, C21.2, C24.2, C25.2, C28.2, C29.2, C30.1, C31.2, D2.C, D4.C, H5.B2,8, H6.B2,8, H7.B2,8, H8.B2,8, IC3.11 (GND), IC3.32 (GND1), IC3.62 (GND2), IC3.81 (GND3), IC3.99 (AGND), ICSP.6, J1.6 (VSS), J1.10 (SHIELD), J1.11 (SHIELD), J1.12 (SHIELD), J1.13 (SHIELD), J2.3, J3.3, J4.3, J5.3, J6.2, L.C, L1.1, R3.2, R5.2, R6.1, R15.1, RN3.4 (1), S1.C1 (NO_1), S1.D1 (NO_2), TR1.2, U1.2 (GND), U1.25 (GND), U2.5 (GND), U3.7 (GND), U4.1, U4.20, U7.2 (GND), U8.15 (GND), U9.2 (GND), U$1.1 (GND), U$2.1 (GND), U$3.1 (IN), X1.5, Y1.2 (GND_1), Y1.4 (GND_2)
M8RXD: RN4.7 (2), U1.21 (TXD)
M8TXD: RN4.8 (2), U1.20 (RXD)
MISO: IC3.22 ((MISO/PCINT3)PB3), ICSP.1, U3.12 (B2), U6.10
MISO3V3: J1.7 (DAT0), U3.3 (A2)
MOSI: IC3.21 ((MOSI/PCINT2)PB2), ICSP.4, U3.13 (B1), U6.11
MOSI3V3: J1.3 (CMD), U3.2 (A1)
unnamed: C20.2, D1.C, U$1.3 (VIN)
unnamed: L.A, RN3.2 (1)
unnamed: D2.A, RN6.6 (2)
unnamed: RN3.6 (2), U1.9 (!RST!)
unnamed: C10.1, U1.16 (VPP)
unnamed: BATT01.+, U2.6 (VBAT)
unnamed: J2.1, RN6.8 (2)
unnamed: J2.2, RN6.7 (2)
unnamed: C22.2, L2.1, U7.6 (SW), U$3.2 (OUT)
unnamed: C22.1, U7.1 (BST)
unnamed: D4.A, RN6.5 (2)
unnamed: C23.1, R3.1, R4.1, U7.3 (FB)
unnamed: C26.1, U8.1 (C1+)
unnamed: C26.2, U8.3 (C1-)
unnamed: C27.1, U8.4 (C2+)
unnamed: C27.2, U8.5 (C2-)
unnamed: C28.1, U8.2 (V+)
unnamed: Q2.1 (G), RN1.8 (2)
unnamed: C29.1, U8.6 (V-)
unnamed: Q1.1 (G), R7.2
unnamed: Q3.1 (G), R8.1, U9.5 (/UV)
unnamed: RN4.3 (1), TX.A
unnamed: RN4.4 (1), RX.A
unnamed: R13.1, R14.2, U9.6 (UVIN)
unnamed: R14.1, R15.2, U9.1 (OVIN)
RD+: R11.2, U1.3 (DP)
RD-: R10.2, U1.4 (DN)
RESET: C1.1, C7.2, D3.A, IC3.30 (RESET), ICSP.5, R9.1, S1.A1 (COM_1), S1.B1 (COM_2)
RX0: IC3.2 ((RXD0/PCIN8)PE0), RN4.2 (1), U5.10
RX1: IC3.45 ((RXD1/INT2)PD2), U5.20, U8.12 (R1OUT)
RX2: IC3.12 (PH0(RXD2)), U5.19
RX3: IC3.63 (PJ0(RXD3/PCINT9)), U5.18
RX232: J5.2, U8.13 (R1IN)
RX-LED: RX.C, U1.13 (GPIO.1)
SCK: IC3.20 ((SCK/PCINT1)PB1), ICSP.3, U3.11 (B3), U6.9
SCK3V3: J1.5 (CLK), U3.4 (A3)
SCL: IC3.43 ((SCL/INT0)PD0), RN1.2 (1), U2.8 (SCL), U6.20
SDA: IC3.44 ((SDA/INT1)PD1), RN1.3 (1), U2.7 (SDA), U6.1
SS: IC3.19 ((SS/PCINT0)PB0), U3.10 (B4), U6.12
SS3V3: J1.2 (CD/DAT3), U3.5 (A4)
TX0: IC3.3 ((TXD0)PE1), RN4.1, U5.11
TX1: IC3.46 ((TXD1/INT3)PD3), U5.1, U8.11 (T1IN)
TX2: IC3.13 (PH1(TXD2)), U5.2
TX3: IC3.64 (PJ1(TXD3/PCINT10)), U5.3
TX232: J5.1, U8.14 (T1OUT)
TX-LED: TX.C, U1.14 (GPIO.0)
USBVCC: C2.1, C8.1, F1.1, Q3.3 (D), U1.7 (REGIN), U1.8 (VBUS), U4.2
USHIELD: L1.2, X1.M1 (S1), X1.M2 (S2), X1.M3 (S3), X1.M4 (S4), Z1.3
VEXT: U4.18
VIN: C21.1, D1.A, J6.1, R1.1, R13.2, U4.19, U7.5 (VIN)
VINSTR: C23.2, C24.1, L2.2, Q1.2 (S), R4.2, R12.1, U4.15
VIO: C9.1, RN3.3 (1), RN4.5 (2), RN4.6 (2), U1.5 (VIO), U1.6 (VDD)
VLIDAR: J4.1, Q1.3 (D)
VSD: C15.1, J1.4 (VDD), Q2.3 (D), U3.1 (VCCA), U3.8 (OE)
XTAL1: C30.2, IC3.34 (XTAL1), Y1.1 (CRYSTAL_1)
XTAL2: C31.1, IC3.33 (XTAL2), Y1.3 (CRYSTAL_2)
XVCC: F1.2, X1.1

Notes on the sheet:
MODULO TARJETA MICRO SD
INTERFAZ RS-232
CONTROL DE POTENCIA
RTC
FUENTE DE PODER (CORE)
CONVERTIDOR DC/DC - VINSTR
LED'S
INTERFACES EXTERIOR
MICROCONTROLADOR
INTERFAZ DE EXPANSIÓN
INTERFAZ USB
TERMISTOR PCB (NTC)



Board: 2 copper layers, 69.6 x 60.1 mm, 98 parts (4 on the bottom side), 121 nets.

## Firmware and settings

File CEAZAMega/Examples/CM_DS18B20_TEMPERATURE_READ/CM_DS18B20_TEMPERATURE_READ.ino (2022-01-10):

/*
 * This sketch is to show you how to read temperature from DS18B20 sensor connected to CEAZAmega board.
 * The built int terminal is powered by D48 MCU pin and the pull-up resistor in data pin (D38) is integrated
 * on board, so is not necesary add any external electronic component to the DS18B20 sensor.
 * The appropiate DS18B20 board terminal is a 3 pin, 2mm pitch JST type with "T°C" marking on PCB to proper detection.
 * 
 * WARNING!
 * Be careful to do not make a short circuit with the sensor power pin to avoid MCU pin damage.
 * 
 * For more details about CEAZAmega board you can see the repository.
 * https://github.com/CEAZAmet/CEAZA-MEGA
 * 
 * You need to install  the library DallasTemperature.h
 * https://github.com/milesburton/Arduino-Temperature-Control-Library
 * 
 */

#include <OneWire.h>
#include <DallasTemperature.h>

// Used pins definition
#define TEMP_EN_PIN   48
#define ONE_WIRE_BUS  38

OneWire oneWire(ONE_WIRE_BUS);
DallasTemperature sensors(&oneWire);

void setup() {
  pinMode(TEMP_EN_PIN,OUTPUT);digitalWrite(TEMP_EN_PIN,HIGH); // Turn-on DS18B20 sensor
  
  Serial.begin(115200);
  Serial.println("\nCEAZA-mega DS18B20 temperature sensor reading!");

  sensors.begin();
}

void loop() {
  // Temperature measurement update
  float ds18b20Temperature = get18B20Temp();

  // Show new data by serial monitor
  Serial.print("DS18B20 Temperature reading: ");
  Serial.print(ds18b20Temperature);
  Serial.println("*C");

  // Validation of data
  if(ds18b20Temperature < -126){
    Serial.println("Invalid read... Have you properly connected the DS18B20 sensor to the board?");
  }

  // wait for next temperature read
  delay(2000);
}


// Dedicated function for read data from DS18B20 connected to board terminal for this prupose 
float get18B20Temp(void){
  digitalWrite(TEMP_EN_PIN,HIGH); delay(10);  // Turn-on the sensor
  sensors.requestTemperatures();              // Update temperature value
  float temp_C = sensors.getTempCByIndex(0);
  digitalWrite(TEMP_EN_PIN,LOW);              // Turn off the sensor
  return temp_C;
}

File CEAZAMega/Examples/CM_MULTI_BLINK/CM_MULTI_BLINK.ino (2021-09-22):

/*
 * This sketch is to show you the LEDs built in CEAZAmega board
 * 
 * For more details about CEAZAmega board you can see the repository.
 * https://github.com/CEAZAmet/CEAZA-MEGA
 * 
 */

// Used pins definition
#define LED_A   40
#define LED_B   41

void setup() {
  pinMode(LED_BUILTIN, OUTPUT);
  pinMode(LED_A, OUTPUT);
  pinMode(LED_B, OUTPUT);

  Serial.begin(115200);
  Serial.println("\nCEAZA-mega multi blink!");

}

void loop() {
  Serial.println("Arduino built in LED blinking");
  for(int i=0;i<30;i++){
    digitalWrite(LED_BUILTIN,!digitalRead(LED_BUILTIN));
    delay(100);
  }
  digitalWrite(LED_BUILTIN,LOW);

  Serial.println("LED_A blinking (duplpicated in LED JST connector)");
  for(int i=0;i<30;i++){
    digitalWrite(LED_A,!digitalRead(LED_A));
    delay(100);
  }
  digitalWrite(LED_A,LOW);

  Serial.println("LED_B blinking (duplpicated in LED JST connector)");
  for(int i=0;i<30;i++){
    digitalWrite(LED_B,!digitalRead(LED_B));
    delay(100);
  }
  digitalWrite(LED_B,LOW);

}

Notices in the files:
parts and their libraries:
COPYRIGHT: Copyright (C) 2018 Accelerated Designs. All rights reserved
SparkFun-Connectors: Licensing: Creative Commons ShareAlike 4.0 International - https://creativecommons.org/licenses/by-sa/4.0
